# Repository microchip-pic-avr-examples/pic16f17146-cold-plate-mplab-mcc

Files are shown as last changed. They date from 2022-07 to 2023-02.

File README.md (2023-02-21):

MCHP (https://www.microchip.com)

# Intelligent Cooling Plate with PIC16F17146

Packed with more peripherals than I/O pins, this intelligent cooling plate — the cold plate — cools its metal surface and anything on top of it. This system is controlled by a single 20-pin, 8-bit microcontroller (MCU), which performs temperature measurements, peltier current monitoring, user interface control and safety functions. The MCU can handle this task single-handedly due to its wide array of Core Independent Peripherals (CIPs).

This README covers a usage guide and a functionality overview of the intelligent cooling plate. This is not an end product, but a demonstration of the expanding capabilities of microcontrollers. Rebuilding this demo in its entirety is possible, but it's purpose is to have pieces of its implementation copied into other practical designs. All Printed Circuit Board (PCB), Computer-Aided Design (CAD) files and nonstandard Bill of Materials (BOM) components are included in the repo for reference. A more in-depth explanation of the functionality listed below can be found in [Application Note AN4889](https://www.microchip.com/en-us/application-notes/an4889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).  

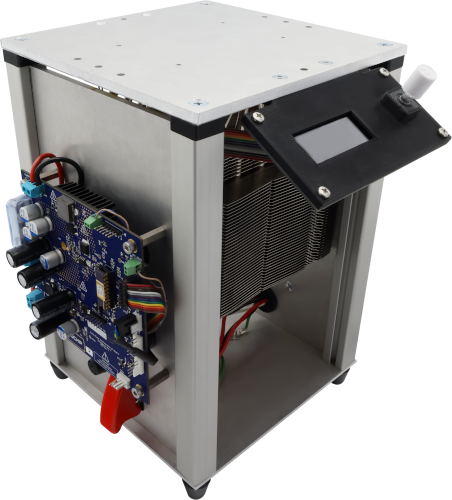
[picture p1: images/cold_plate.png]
The Cold Plate


## Related Documentation
- [PIC16F17146 Family](https://www.microchip.com/en-us/products/microcontrollers-and-microprocessors/8-bit-mcus/pic-mcus/pic16f17146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)
- [EA OLEDM204 Data Sheet](https://www.lcd-module.de/fileadmin/html-seiten/eng/pdf/doma/oledm204-ae.pdf)
- [CP85435 Peltier Plate Data Sheet](https://www.cuidevices.com/product/resource/cp85.pdf)
- [PS103J2 NTC Thermistors](https://www.littelfuse.com/products/temperature-sensors/leaded-thermistors/interchangeable-thermistors/standard-precision-ps/ps103j2.aspx)

## Software Used
- [MPLAB&reg; X IDE v6.0.5](https://www.microchip.com/en-us/tools-resources/develop/mplab-x-ide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) or newer
- [MPLAB XC8 v2.36.0](https://www.microchip.com/en-us/tools-resources/develop/mplab-xc-compilers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) or newer
- [MPLAB Code Configurator](https://www.microchip.com/en-us/tools-resources/configure/mplab-code-configurator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) (MCC)
- [MPLAB Mindi&trade; Analog Simulator](https://www.microchip.com/en-us/tools-resources/develop/analog-development-tool-ecosystem/mplab-mindi-analog-simulator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)

## Development Hardware Used

- [PIC16F17146](https://www.microchip.com/en-us/product/PIC16F17146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)
- [Curiosity Development Board (DM164137)](https://www.microchip.com/en-us/development-tool/DM164137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) (used during development)

## Major Functions
These are the major functions that are implemented on the microcontroller.

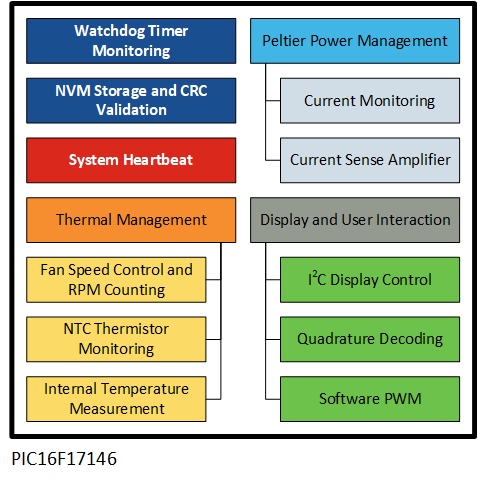
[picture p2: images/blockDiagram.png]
Block Diagram


**Current Monitoring and Measurement**  
- Integrated Operational Amplifier (OPAMP1)  
- Analog Comparators 1 and 2 (CMP1 and CMP2)  
- Digital-to-Analog Converters 1 and 2 (DAC1, DAC2) 
- Analog-to-Digital Converter with Computation (ADCC)
- Fixed Voltage Reference (FVR)

OPAMP1 is implemented as a current-sense amplifier, which outputs a magnified version of the small voltage across the current shunt resistor. The output of OPAMP1 is also used internally for monitoring and measurement. 

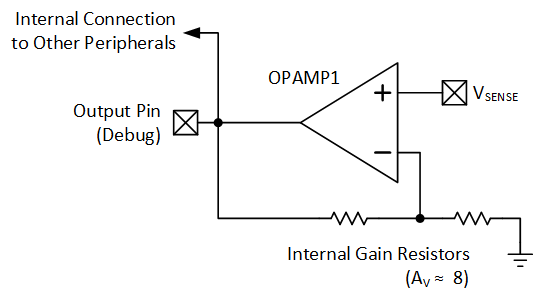
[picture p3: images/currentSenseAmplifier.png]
Current Sense Amplifier
  

The amplified current sense output of OPAMP1 is compared to a small, set voltage level (from DAC1) using CMP1. If the output is greater, then CMP1 is high, indicating current is flowing through the system.

DAC2/CMP2 work in the same way, but are used to detect overcurrent. If the DAC2 value is exceeded by the output of OPAMP1, the MCU shuts down the Peltier plate.

Additionally, the current is measured for telemetry by the ADCC, with the FVR providing the appropriate voltage reference.

**Cold Plate, Heat Sink, and MCU Temperature Monitoring**
- Analog-to-Digital Converter with Computation (ADCC)
- Fixed Voltage Reference (FVR)
- Temperature Indicator Module (TEMP)

The microcontroller measures the temperature of the top plate and its heat sink using Negative Temperature Coefficient (NTC) thermistors. It also monitors the internal temperature of the MCU die with the TEMP peripheral. The ADCC uses the FVR to ensure measurements are stable, and to provide the appropriate voltage for the TEMP peripheral. 

**Functional Safety Supported Setting Storage**
- Cyclic Redundancy Check (CRC) with Memory Scanner 
- Nonvolatile Memory (NVM) Control

Using the NVM and CRC CIPs, user settings are saved to EEPROM along with a CRC checksum. On start-up, the checksum is revalidated for data integrity. The CRC reduces code size and runs faster than the software could perform, by offloading it to the dedicated hardware.
 
**Protective System Monitoring**
- Timer 0 (TMR0)
- Windowed Watchdog Timer (WWDT)

Since the cold plate involves high currents and potentially hazardous temperatures, the WWDT is used to ensure periodic monitoring of the device is performed. If the WWDT is not triggered within a specific amount of time, the MCU resets. This way, if the firmware deadlocks, the system does not remain active, thus making sure safety is not compromised. TMR0 generates the base timing for the periodic self-check.

**Single-Speed Fan Control with Dual Fan Speed Monitoring**
- Pulse Width Modulator with Compare 2 (PWM2)
- Timer 2 (TMR2) and Timer 4 (TMR4)

To cool the Peltier plate, a PWM CIP is used to generate a speed control signal for the system fans. This allows the fans to ramp up and down depending on the conditions of the system. Additionally, the tachometer signals from the fans are monitored and counted by TMR2 and TMR4. If Fan 1 is not spinning (or stops spinning), the microcontroller will not power up the Peltier plate. 

**User Interface**
- Host Synchronous Serial Port 1 (MSSP1), in I<sup>2</sup>C mode
- Timer 1 (TMR1) and Timer 3 (TMR3)
- Configurable Logic Cell 1 and 2 (CLC1 and CLC2)
- Pulse Width Modulator with Compare 1 (PWM1)

The user interacts with the cold plate through a push button rotary encoder and an OLED display. The OLED is controlled with an on-chip MSSP1 peripheral via I<sup>2</sup>C. Since there is dedicated MSSP hardware, the CPU can load data into the module, rather than bit-banging the I/O lines. 

The rotary encoder inputs connect into two CLC CIPs to convert the signals into clockwise and counter-clockwise pulses (depending on direction). The pulses go into TMR1 and TMR3, which act as counters. The CPU can read the counters later to calculate the net rotation.

Lastly, the rotary encoder has two built-in LEDs—an orange and a blue LED. Using PWM1, these LEDs are used for a visual indication of the cold plate status:

| Color | Cold Plate Status |
| --- | --- |
| Breathing Purple | Standby |
| Breathing Blue | Actively Cooling |
| Solid Blue | At the Target Temperature |
| Solid Orange | Error |

**Debug Print**
- Enhanced Universal Synchronous Asynchronous Receiver
Transmitter (EUSART1)

EUSART1 is used to transmit debug messages from the MCU. It is set up to run at 115200 baud, 8 data bits and 1 stop bit.

## Operation

On boot, a standby screen shows the current plate temperature, the set temperature, and whether the product is in demo mode (which limits the lowest temperature for safety).

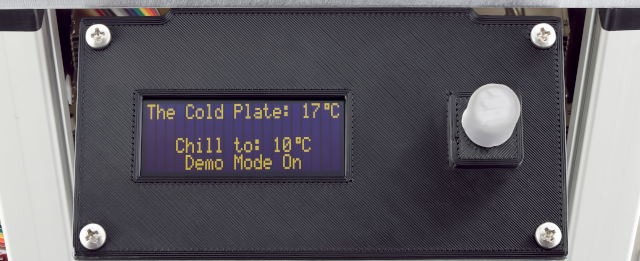
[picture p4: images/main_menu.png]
Main Menu


Pressing the rotary encoder button brings up a menu that can be used to change various running parameters:

| Name | Function |
| --- | --- |
| Go Back | Returns to Standby screen |
| Start | Turns on plate, goes to running status screen |
| Set Temperature | Changes target temperature |
| Hysteresis | Configures temperature hysteresis |
| Change Units | Selects Celsius or Fahrenheit units|
| Show Icons | Displays text or icons in running status screen |
| About | Lists developer and version info |
| Demo Mode Toggle | Password protected way to disable demo mode|

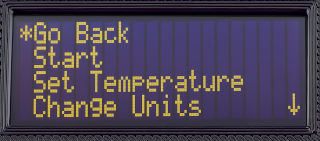
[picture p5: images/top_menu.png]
Top Menu

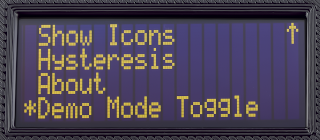
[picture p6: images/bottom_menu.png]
Bottom Menu


Upon pressing Start, the MCU begins checking for various errors. If all checks pass, the plate power is enabled and the user is brought to a running status screen which shows:

- Target temperature of the plate
- Current temperature of the plate
- MCU temperature
- Current Peltier current
- Cooling fan RPM

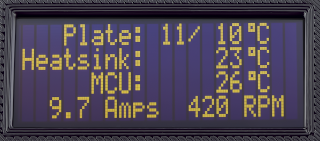
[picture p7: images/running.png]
Running Menu


If an error occurs, power to the plate is cut, and a troubleshooting error message displays on the screen. Press the rotary encoder to clear the error and return to the standy screen. If the error is not remedied and the plate is started again, it will loop back to the same error screen.

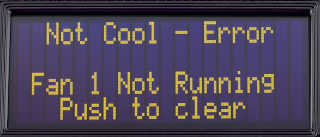
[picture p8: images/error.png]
Error Menu


Below is a list of the various possible errors that are continuously checked for during running operation:

| Name | Error Code | Cause |
| ---- | --- |--- |
| PELTIER_FAN1_ERROR | 1 | The heat sink fan is unplugged |
| PELTIER_OVERCURRENT_ERROR | 2 | More current is pulled than the software allows |
| PELTIER_POWER_ERROR | 3 | No power is detected when the plate should be pulling current |
| PELTIER_GAIN_ERROR | 4 | The gain of the operational amplifier exceeds expected tolerance
| PELTIER_INT_OVERHEAT | 5 | Internal MCU temperature is too hot (70&deg;C)|
| PELTIER_HEATSINK_OVERHEAT | 6 | Heat sink is too hot (80&deg;C)|
| PELTIER_SENSE_HOT_OPEN | 7 | Thermistor for the heat sink is disconnected |
| PELTIER_SENSE_COLD_OPEN | 8 | Thermistor for the plate temp is disconnected |
| PELTIER_PLATE_TEMP_LIMIT | 9 | Cold plate is below safe temperature |
| PELTIER_EEPROM_WRITE_FAIL | 10 | Internal EEPROM written value does not match read value. |

Once started, pressing the rotary encoder button and selecting `Cancel` stops the plate and returns to the standby menu.

## Summary
This README covered a brief overview of the functionality of the cold plate and how to operate it.

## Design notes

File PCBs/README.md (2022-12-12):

# Important Information about PCBs

- Only Rev A was tested, Rev B has not been tested.
    - Power stage on Rev A was modified for linear topology.
    - Recommended to build Rev B, not A
- Thermal conductors are for testing purposes. 
    - Only THM_C1 is needed for an implemented function (implementing OTP on the PCB).

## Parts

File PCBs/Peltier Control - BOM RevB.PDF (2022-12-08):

Comment | Value | Footprint | Part Number | Designator | Quantity
Capacitor | 0.1uF | 0805 | | C1, C9, C13, C30 | 4
Electrolytic Capacitor | 270uF | 12.5mm Electrolytic Capacitor | 100ZLJ220M12.5X25 | C2, C5, C10, C15 | 4
Capacitor | 10uF | 0805 | | C3, C4, C19, C28 | 4
Electrolytic Capacitor | 22uF | 10mm Electrolytic Capacitor | A759MS226M2AAAE045 | C6, C11, C16, C20, C34 | 5
Capacitor | 1uF | 1206 | | C7, C8 | 2
Capacitor | 10uF | 1210 | | C12 | 1
Capacitor | 330nF | 0805 | | C17 | 1
Capacitor | 1uF | 0805 | | C22, C24, C25, C27, C29, C31 | 6
Capacitor | DNP | 0805 | | C32, C33 | 2
48V - 15V | | TB002-500-02BE | TB002-500-02BE | CONTROL PWR, PELTIER PWR | 2
LED | | 0805 for LED | | D2, D4, D5, D6 | 4
Schottky | | SOD-128 | PMEG6030EVPX | D3 | 1
Diode | | SOT-23-3 | BAS16LT1G | D8, D10 | 2
Connect to Earth | | TB002-500-02BE | TB002-500-02BE | EARTH CONN | 1
ESD Diode Array | | SOIC-16 | SP720ABG | ESD1 | 1
Fuse | | 4250 Fuse Holder | 4250 | F1 | 1
Fuse | | 1206 Fuse | SF-1206S300W-2 | F2 | 1
Fan Header | | 0470531000 | | FAN1, FAN2 | 2
SMD Metal Jumper on PCB | | 0805 PCB Jumper | | J1, J2 | 2
Inductor | 5.2uH | CDRH104R | CDRH104RNP-5R2NC | L3 | 1
2-Pos Terminal Block | | 691210910002 | 691210910002 | NTC_COLD, NTC_HOT | 2
To Peltier Plate(s) | | TB002-500-02BE | TB002-500-02BE | PELTIER_CONN | 1
PICKIT 4 Header | | HDR1X6 | | PICKIT | 1
PTC Fuse | 200mA | PTC 0805 | MF-PSHT020KX-2 | PTC1, PTC2 | 2
PTC Fuse | 50mA | PTC 0805 | MF-PSHT005KX-2 | PTC5, PTC6 | 2
NMOS | | TO-252 | FDD390N15ALZ | Q1 | 1
Resistor | 10k | 0805 | | R1, R6, R13, R14, R16, R22, R23, R25 | 8
Resistor | 470 | 0805 | | R2 | 1
Resistor | 1k | 0805 | | R3, R24 | 2
Resistor | 4.7k | 0805 | | R4, R7, R8 | 3
Resistor | 10m | Wide 1206 | CSNL1206FT1L00 | R5 | 1
Resistor | 27k | 0805 | | R9, R10, R19, R28 | 4
Resistor | 0 | 0805 | | R11, R12 | 2
Resistor | 140k | 0805 | | R15 | 1
Resistor | 100 | 0805 | | R17, R18, R26, R27 | 4
NTC | 10k @ 25C | 0805 | SM103J1K | R20 | 1
Resistor | DNP | 0805 | | R21 | 1
Resistor | 2.2k | 0805 | | R29 | 1
SPST Switch | | PTS636-THT | | RST_SW | 1
Header 6 | | HDR1X6 | | SERIAL_DEBUG | 1
Thermal Conductor | | 0805 | QB0805A40WYTD | THM_C1, THM_C2, THM_C3 | 3
Test Point | | Test Point, 40mil hole | 526x, [NoValue] | TP1, TP2, TP5, TP6, TP7, TP8, TP12, TP13, TP14, TP15, TP19, TP20, TP21, TP22 | 14
Test Point | | Test Point, 60mil SMD | | TP16, TP17, TP18 | 3
MCP1754S | | SOT-223-3 | MCP1754ST-5002E/DB | U1 | 1
PIC16F17146 | | PDIP-20 | | U2 | 1
TC1413(N), MOSFET Driver | | SOIC-8 | TC1413N | U3 | 1
MCP6566 | | SOT23-5 | | U4 | 1
MCP16363 | | VDFN 3x3x0.9 | MCP16363T-E/NMX | U6 | 1
Header 6X2 | | HDR2X6 | | UI_BOARD_CONN | 1
Zener | 7.5V | SOT-23-3 | BZX84B7V5-7-F | Z2 | 1

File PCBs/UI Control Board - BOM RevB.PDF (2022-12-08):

Comment | Value | Footprint | Quantity | Designator
3 Position SMD Jumper | | 3 Position 0805 | 2 | J1, J2
Capacitor | 0.1uF | 0805 | 4 | C1, C2, C5, C6
Capacitor | 2.2uF | 0805 | 2 | C3, C4
Capacitor | 10uF | 0805 | 2 | C9, C10
Capacitor | DNP | 0805 | 3 | C7, C8, C11
Header 2 | | HDR1X2 | 1 | EXT_BUTTON
Header 6X2 | | HDR2X6 | 1 | UI_BOARD_CONN
LED | | 0805 for LED | 4 | D1, D2, D3, D4
Mechanical Encoder with 2 LEDs and Switch | | PEL12D-4xxxS-Sxxxx | 1 | ENC1
OLED 4x20 Character Display | | EA OLEDM204 | 1 | DISP1
Resistor | 0 | 0805 | 1 | R8
Resistor | 1k | 0805 | 5 | R9, R10, R11, R12, R13
Resistor | 2.7k | 0805 | 1 | R14
Resistor | 10k | 0805 | 6 | R1, R3, R4, R5, R6, R7
Resistor | 910k | 0805 | 1 | R2
Resistor | DNP | 0805 | 2 | R15, R16
SPST Switch | | PTS636-THT | 1 | DISP_RST
Test Point | | Test Point, 60mil SMD | 5 | TP1, TP2, TP3, TP4, TP5

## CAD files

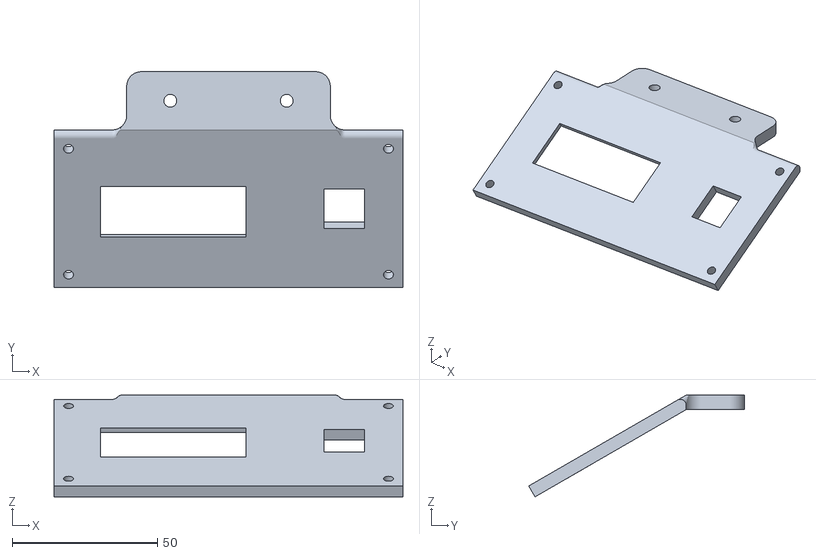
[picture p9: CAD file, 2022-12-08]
3D Prints/UI_mount.obj
120.0 x 74.1 x 35.0

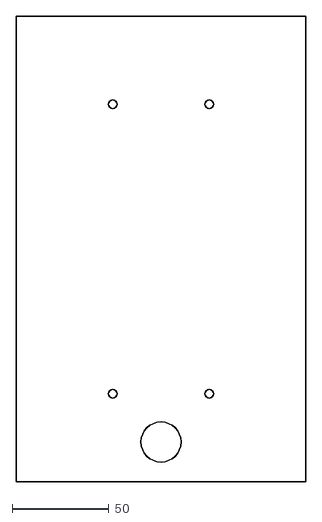
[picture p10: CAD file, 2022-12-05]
Mechanical Plates/PSU Mounting.dxf
150.0 x 241.3

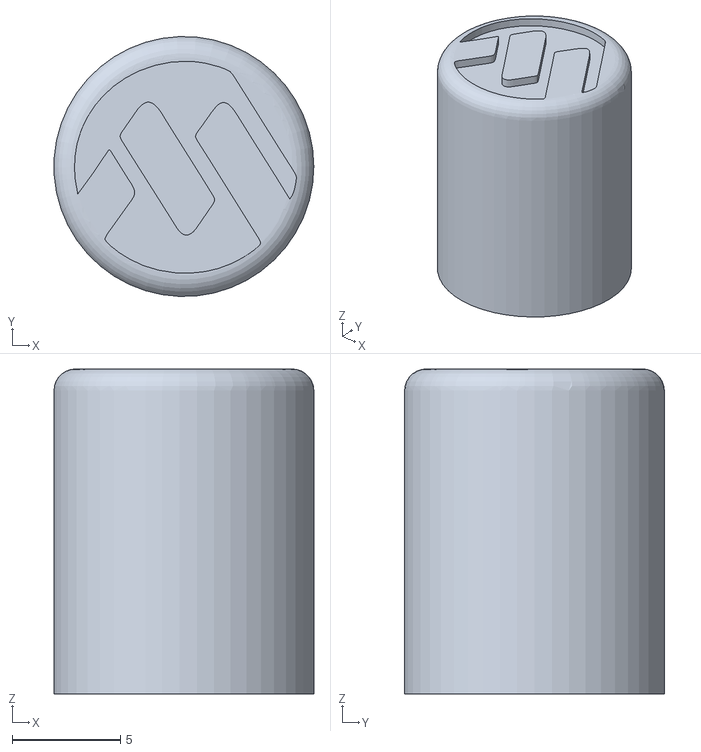
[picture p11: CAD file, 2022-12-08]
3D Prints/encoder_knob.obj
12.0 x 12.0 x 15.0

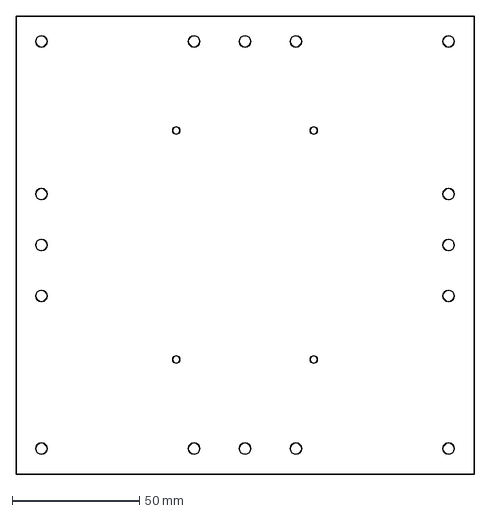
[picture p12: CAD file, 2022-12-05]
Mechanical Plates/Top Plate.dxf
180.0 x 180.0 mm

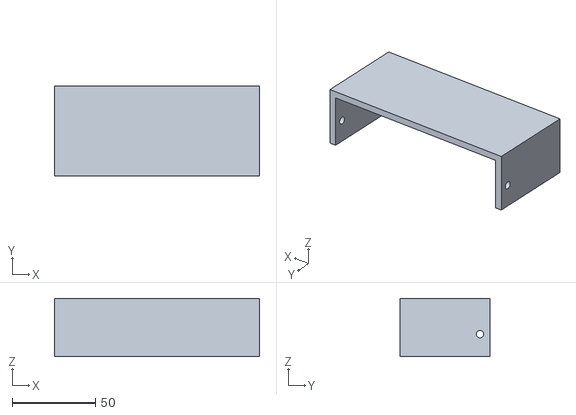
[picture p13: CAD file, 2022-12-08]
3D Prints/power_supply_cover.obj
123.0 x 54.0 x 35.0

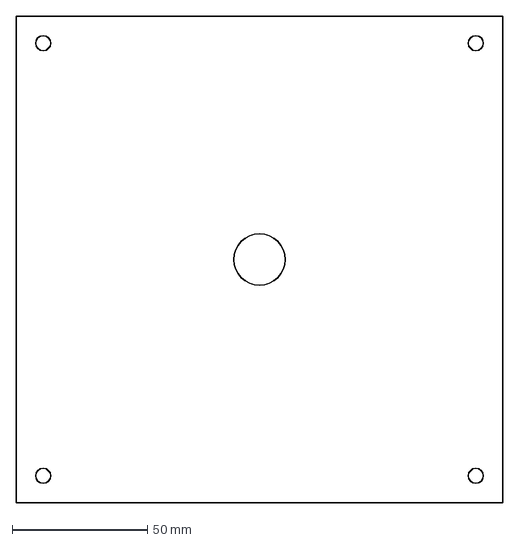
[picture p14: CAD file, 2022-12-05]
Mechanical Plates/Bottom Plate.dxf
180.0 x 180.0 mm

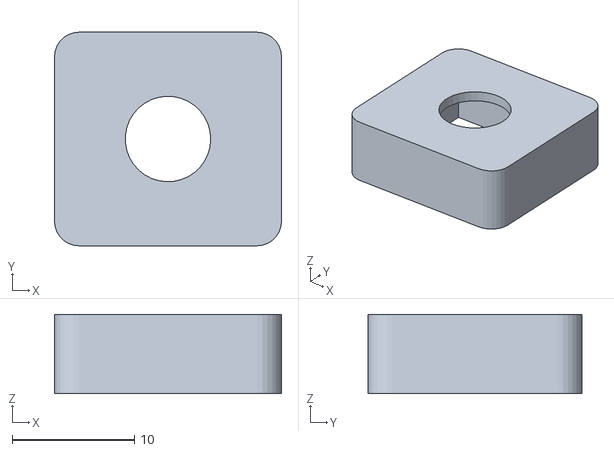
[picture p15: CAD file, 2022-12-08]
3D Prints/encoder_cover.obj
18.6 x 17.5 x 6.50

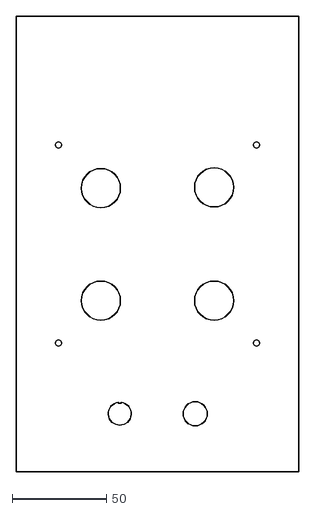
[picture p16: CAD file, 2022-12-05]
Mechanical Plates/PCB Mounting.dxf
150.0 x 241.3

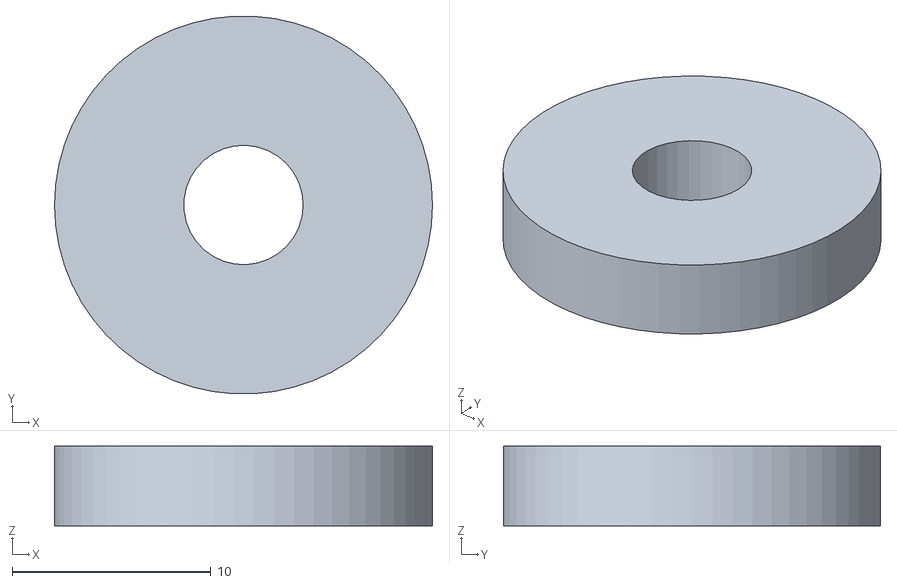
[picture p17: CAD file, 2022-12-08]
3D Prints/rubber_feet_spacer.obj
19.0 x 19.0 x 4.00

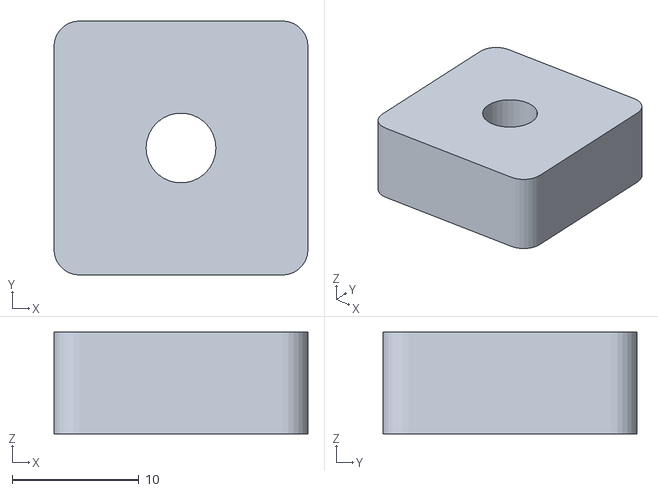
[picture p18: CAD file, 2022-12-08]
3D Prints/temperature_spacer.obj
20.0 x 20.0 x 8.00

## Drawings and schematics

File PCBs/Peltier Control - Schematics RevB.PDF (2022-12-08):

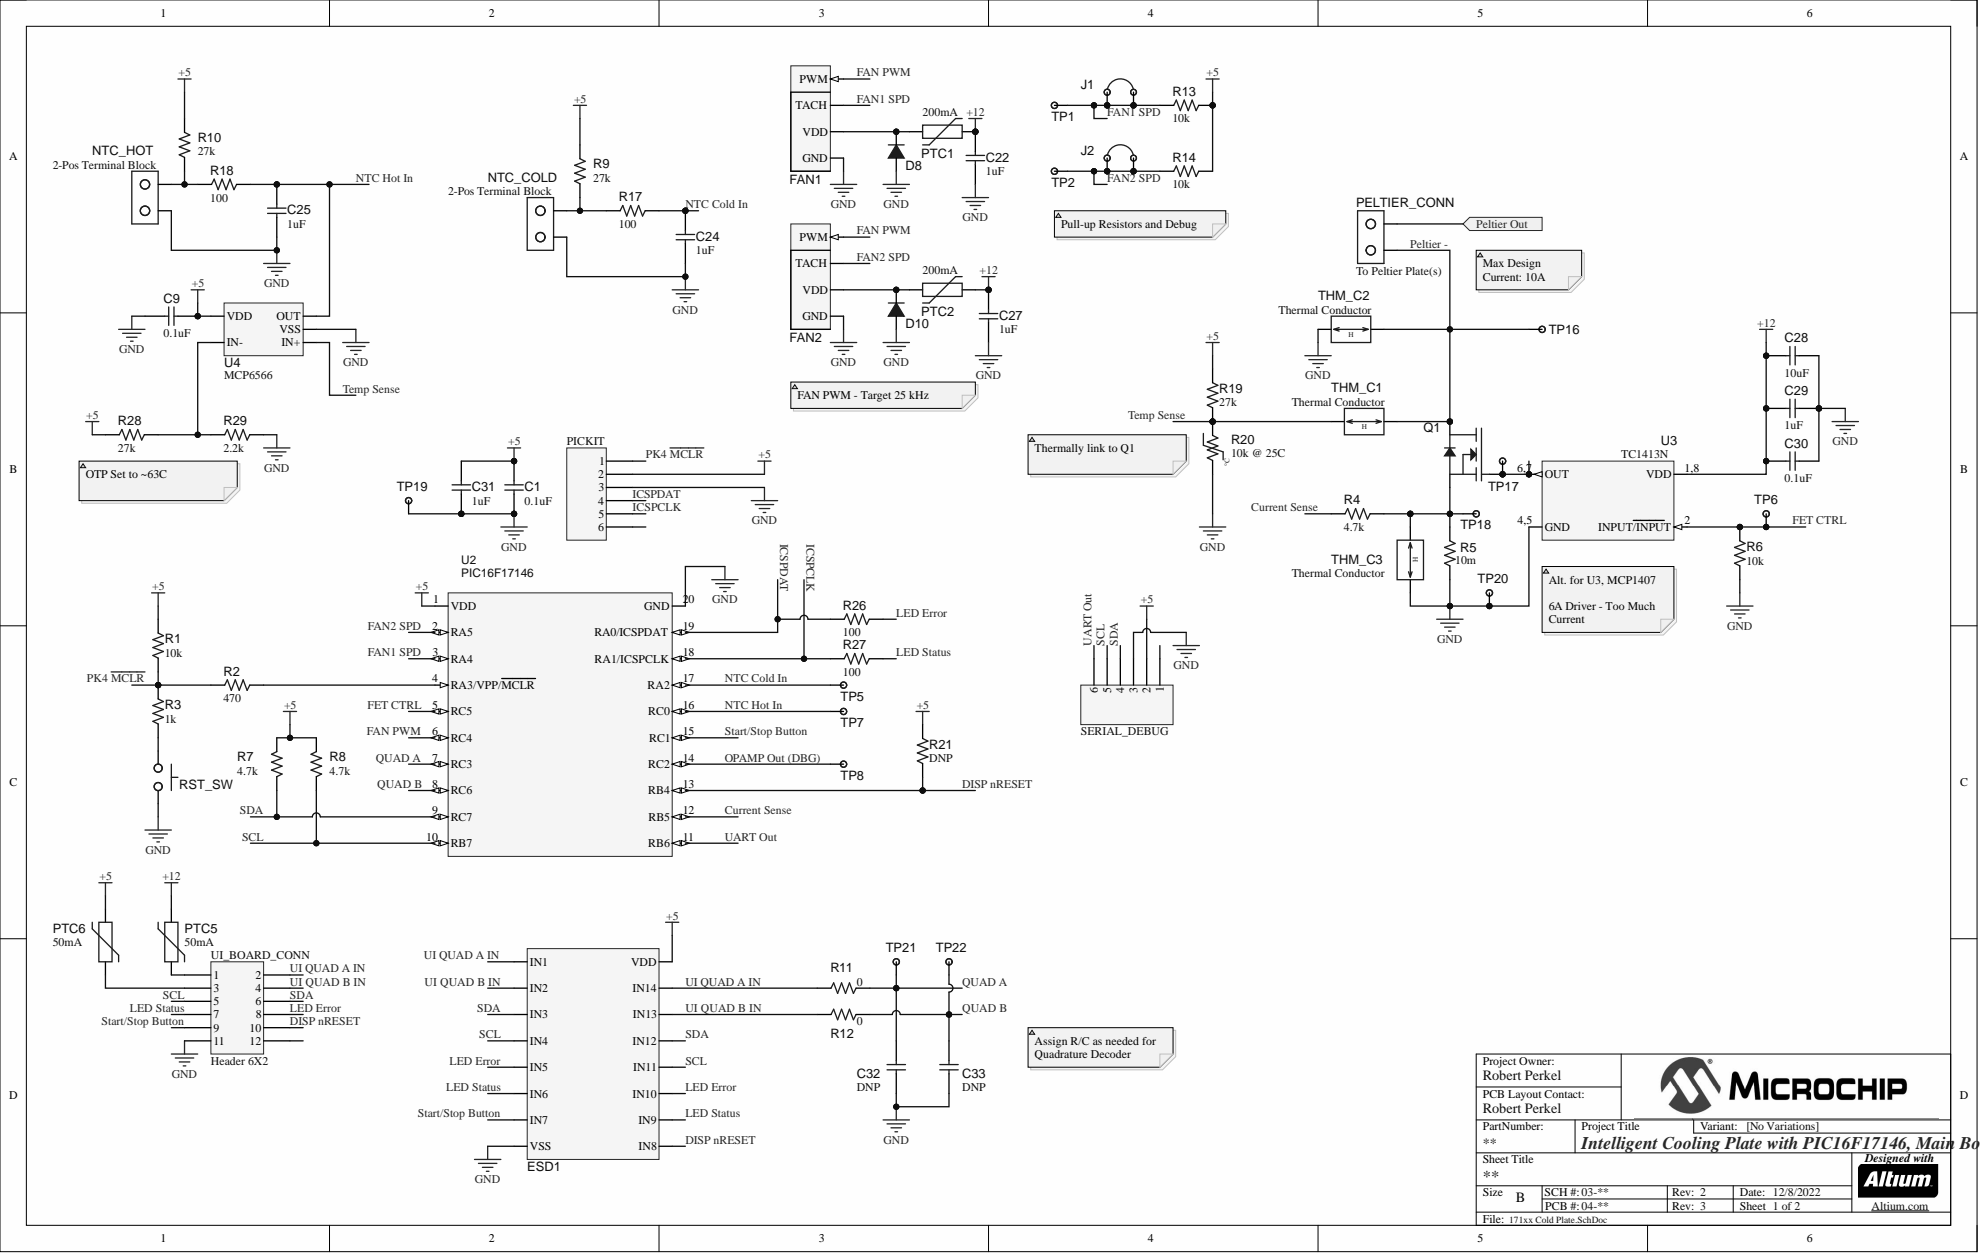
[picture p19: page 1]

Pull-up Resistors and Debug

FAN PWM - Target 25 kHz

Assign R/C as needed for
Quadrature Decoder

Project Title
Intelligent Cooling Plate with PIC16F17146, Main Board

Sheet Title ** | Designed with Altium.com

Size B | SCH #: 03-** | Rev: 2 | Date: 12/8/2022

PCB #: 04-** | Rev: 3 | Sheet

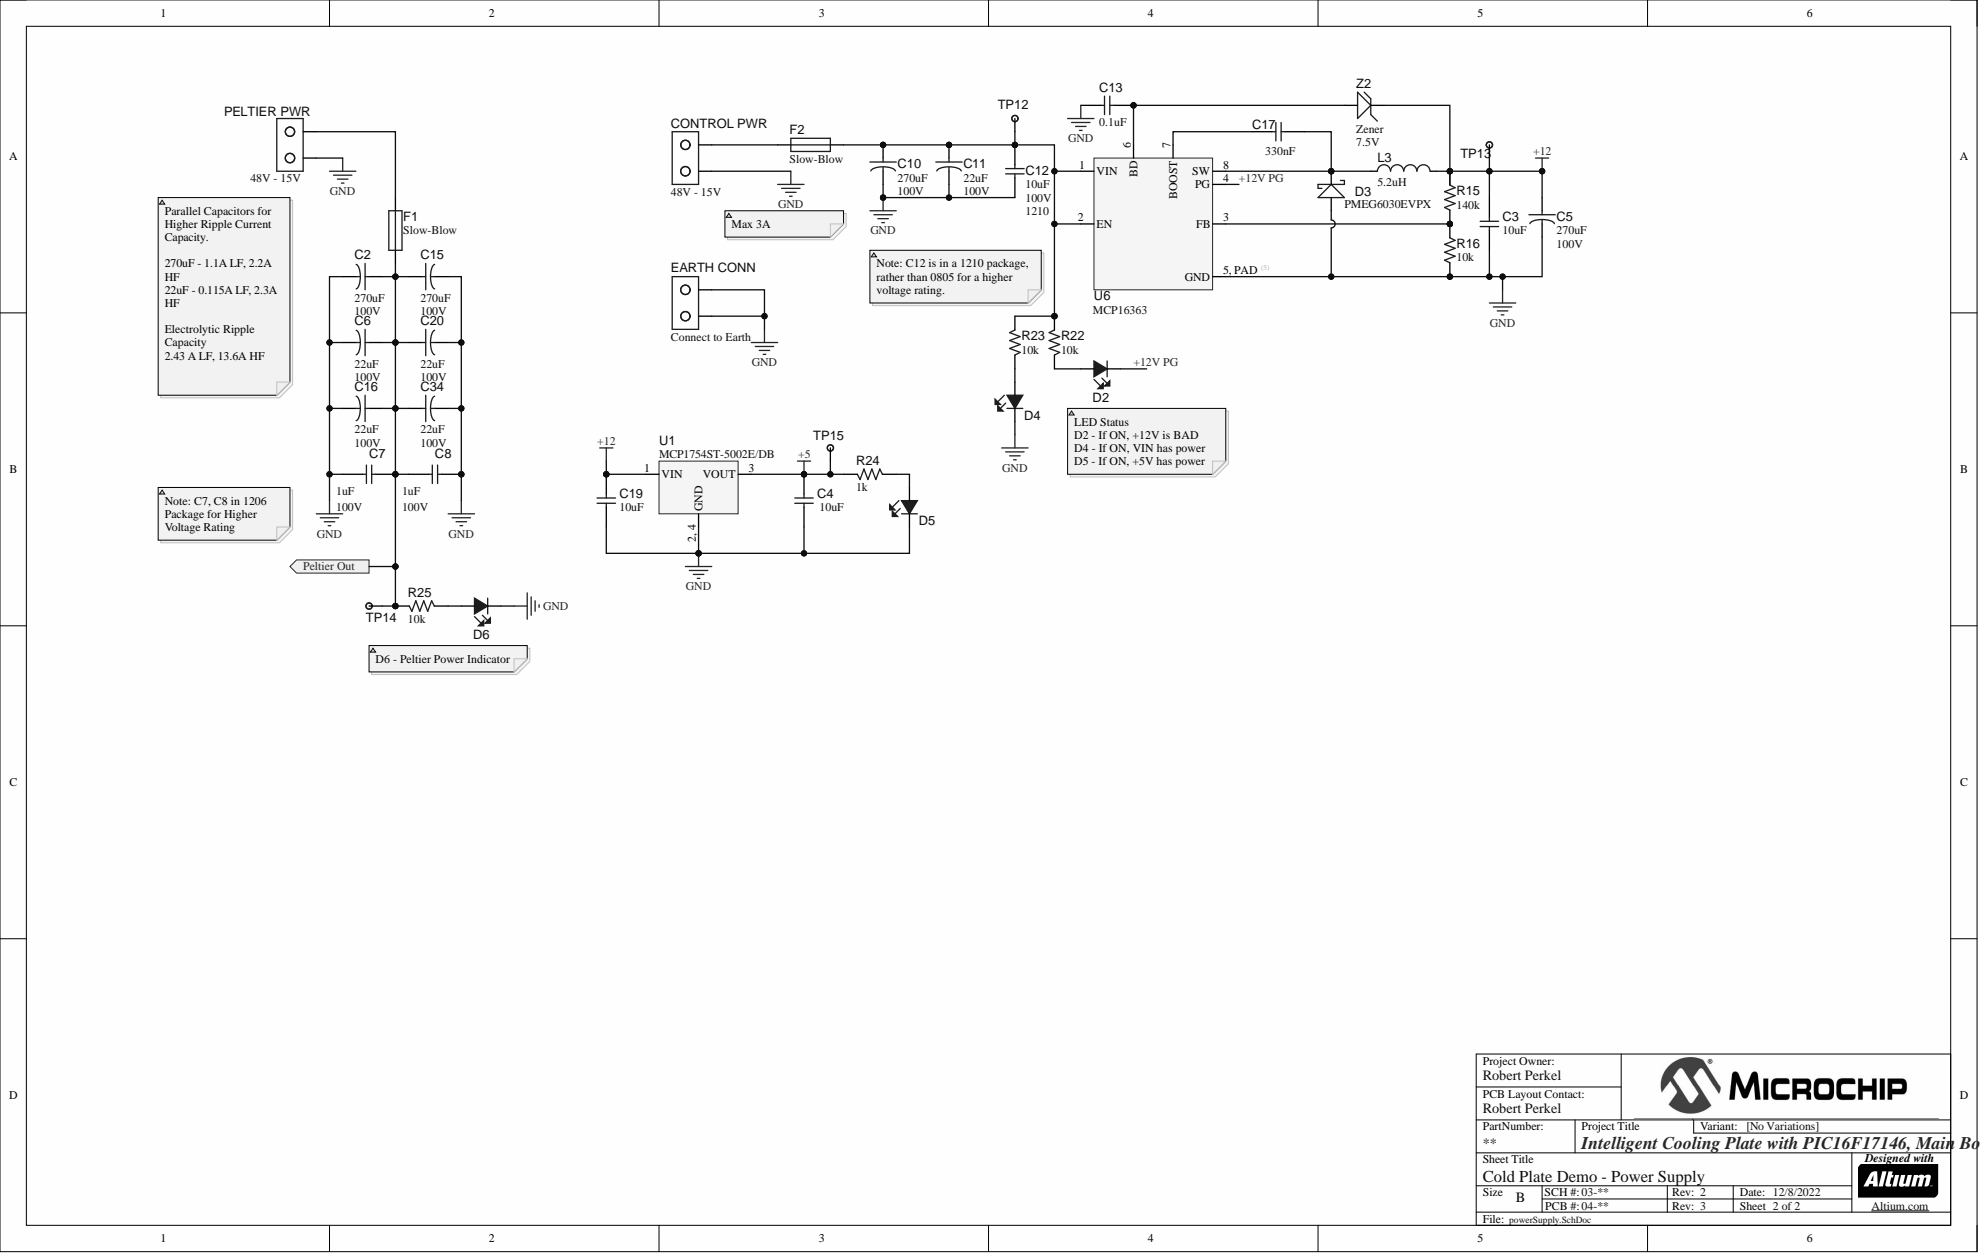
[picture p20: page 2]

Note: C12 is in a 1210 package,
rather than 0805 for a higher
voltage rating.

LED Status
D2 - If ON, +12V is BAD
D4 - If ON, VIN has power
D5 - If ON, +5V has power

Project Title
Intelligent Cooling Plate with PIC16F17146, Main Board

Sheet Title Cold Plate Demo - Power Supply | Designed with Altium.com

Size B | SCH #: 03-** | Rev: 2 | Date: 12/8/2022

PCB #: 04-** | Rev: 3 | Sheet

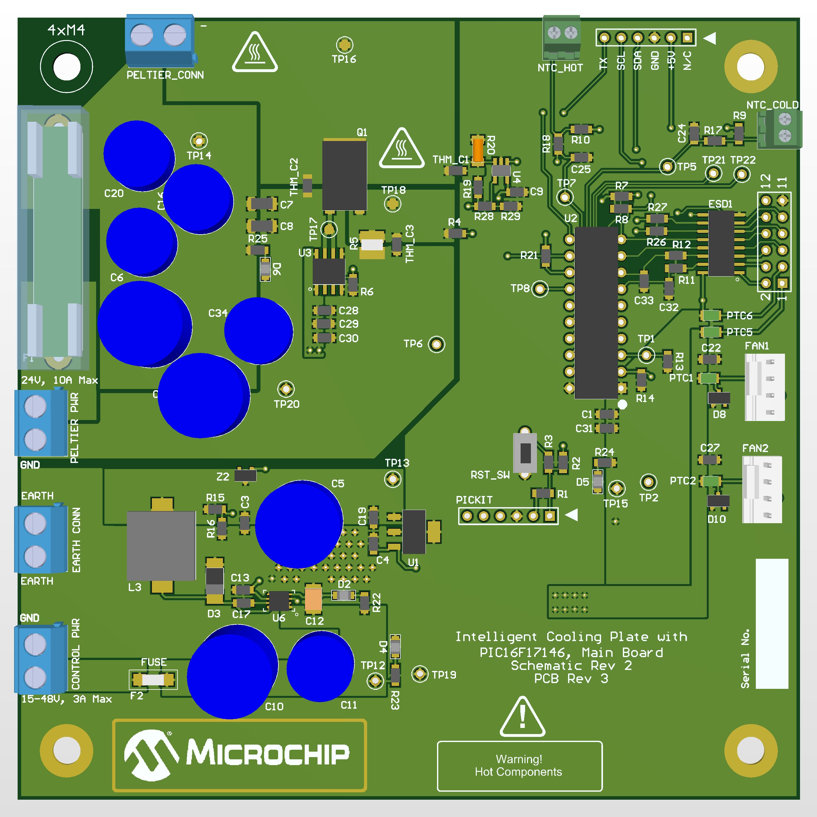
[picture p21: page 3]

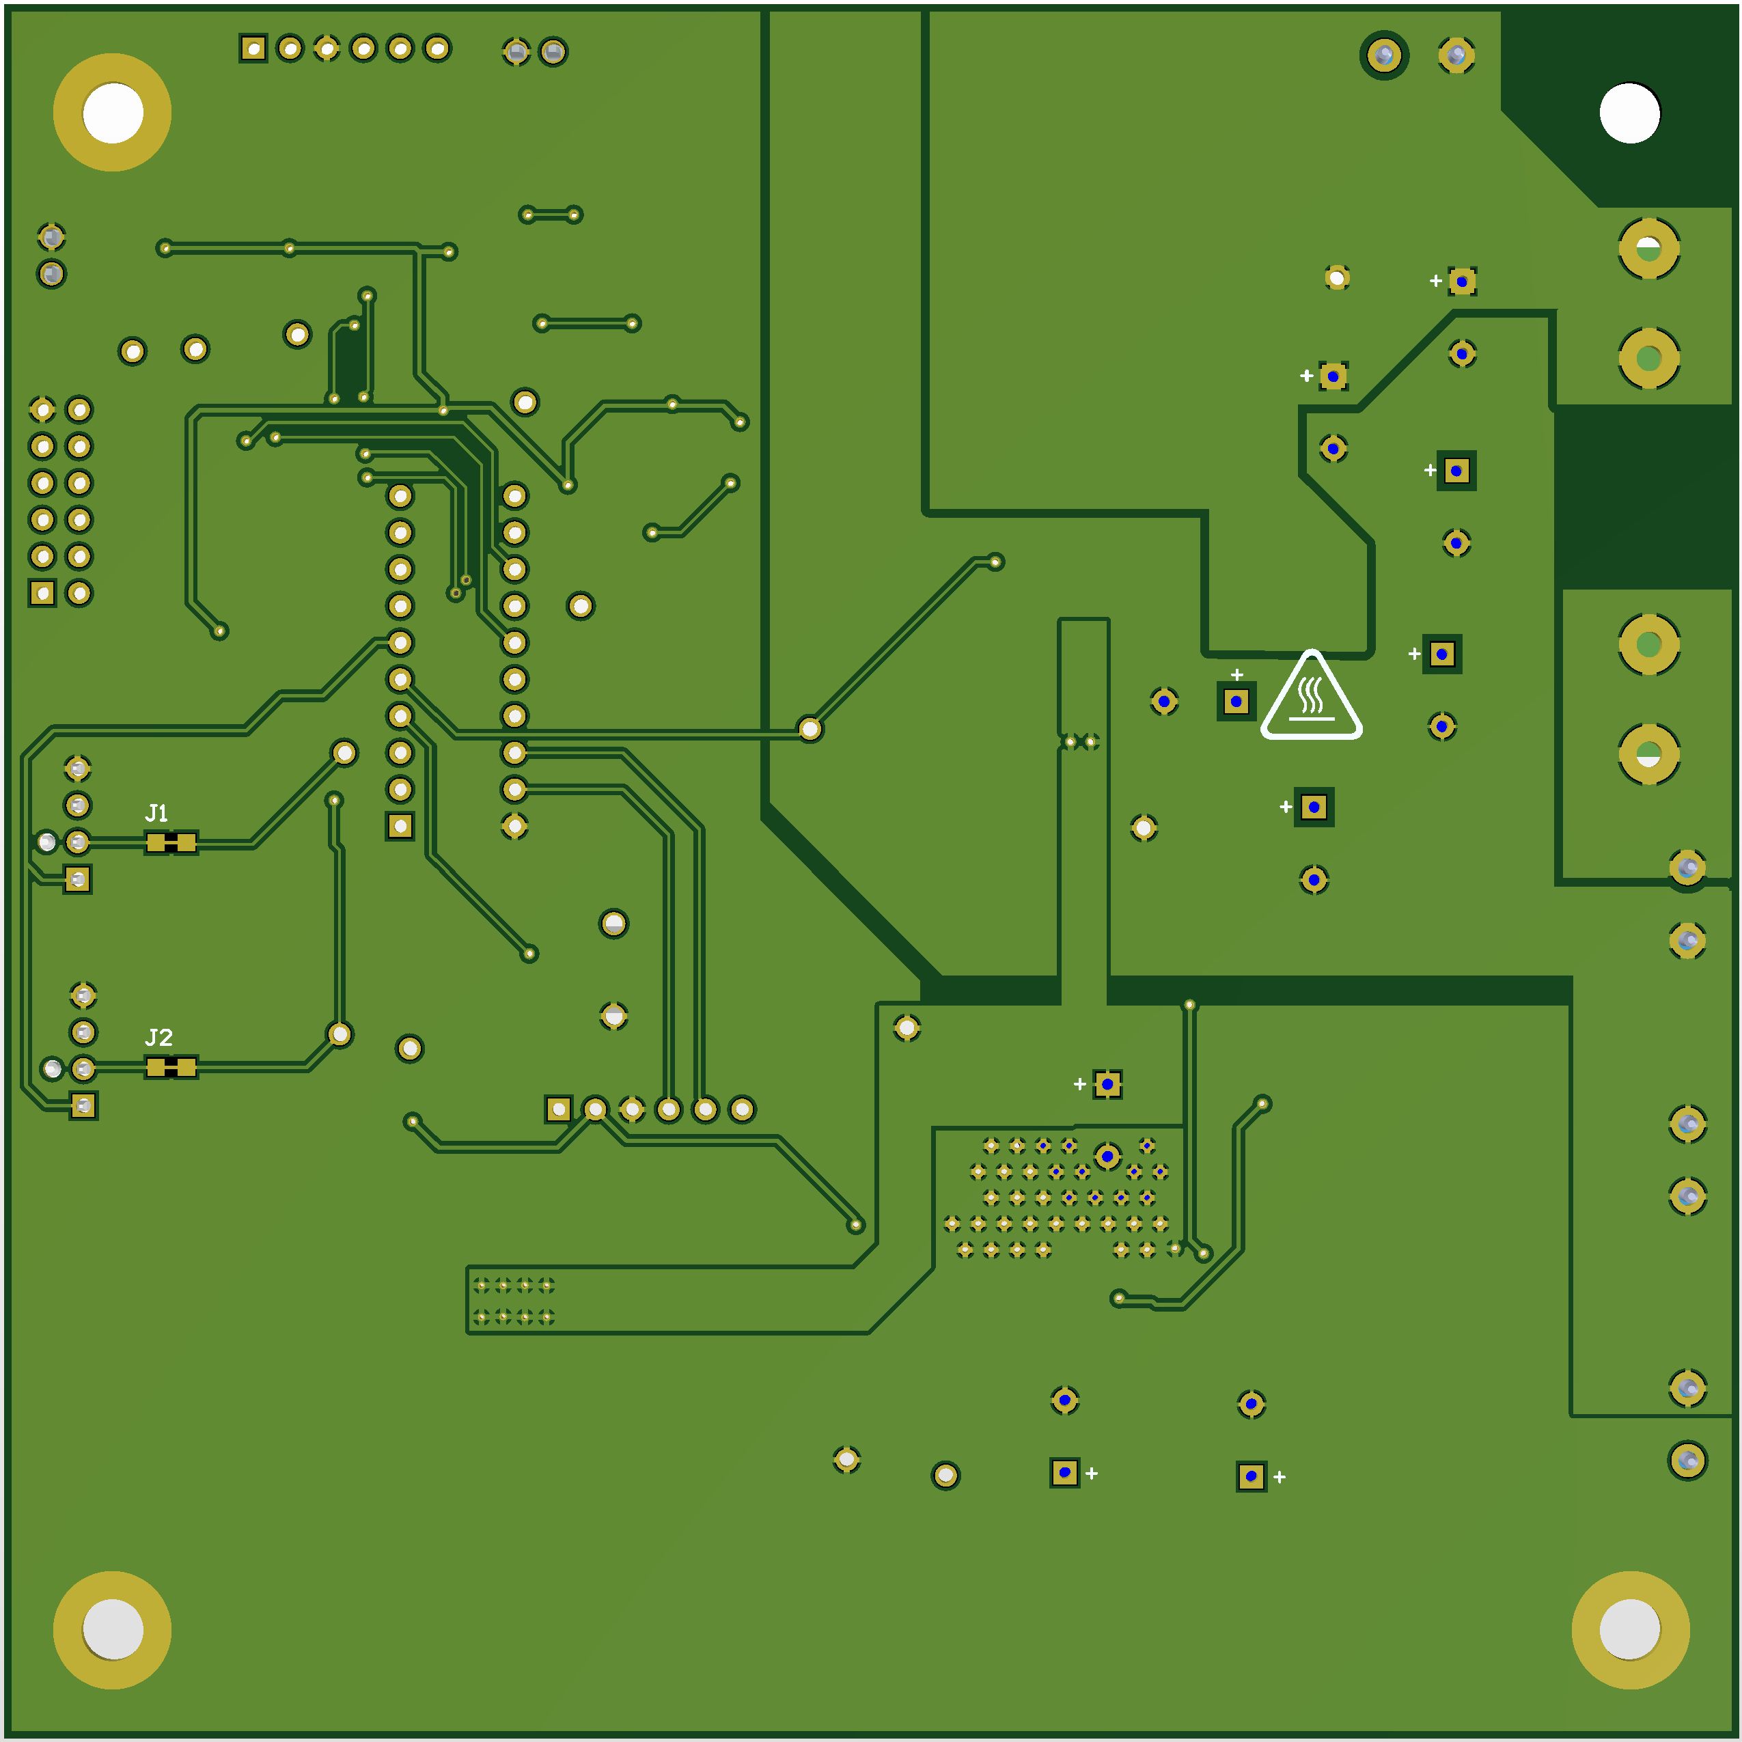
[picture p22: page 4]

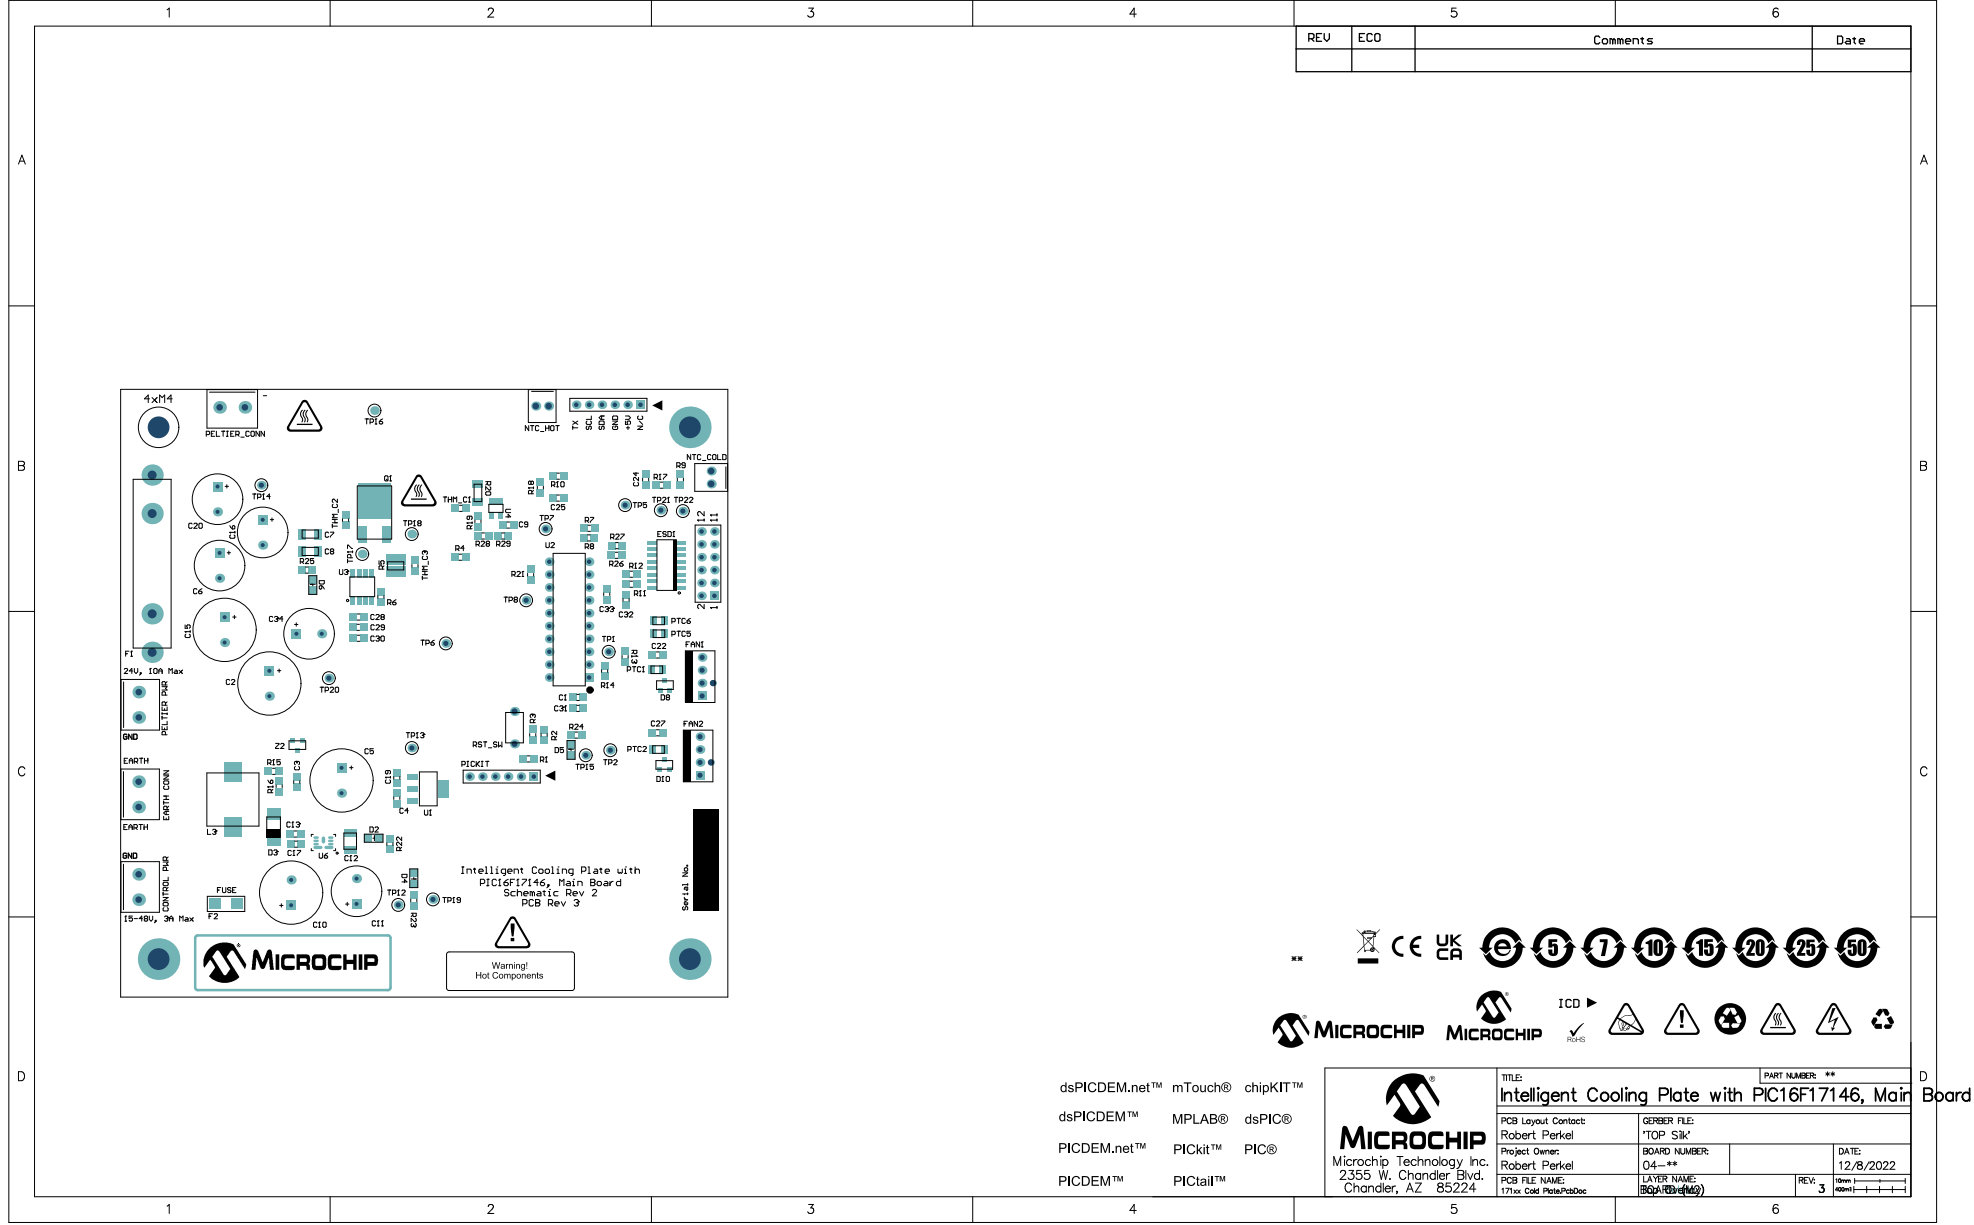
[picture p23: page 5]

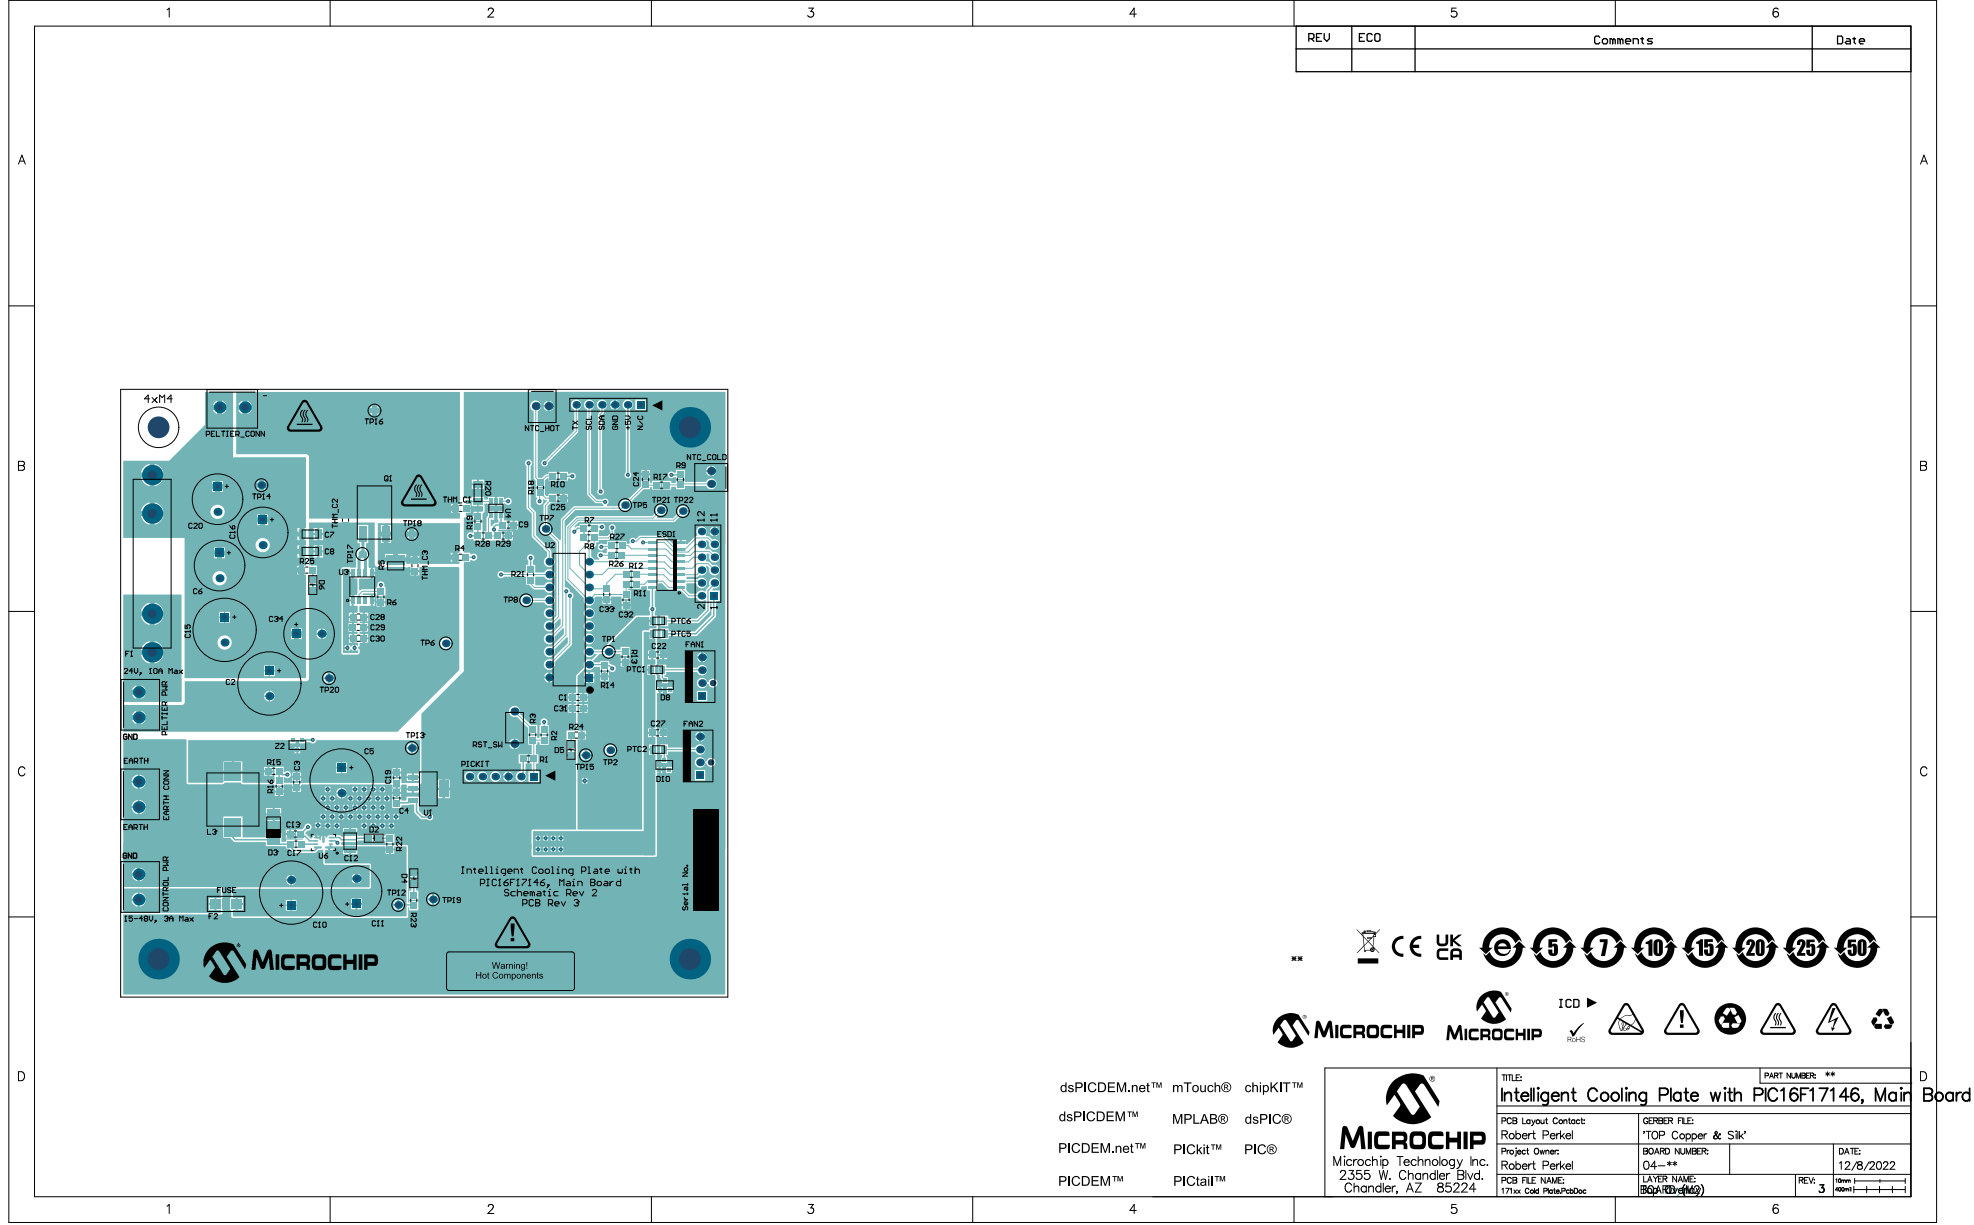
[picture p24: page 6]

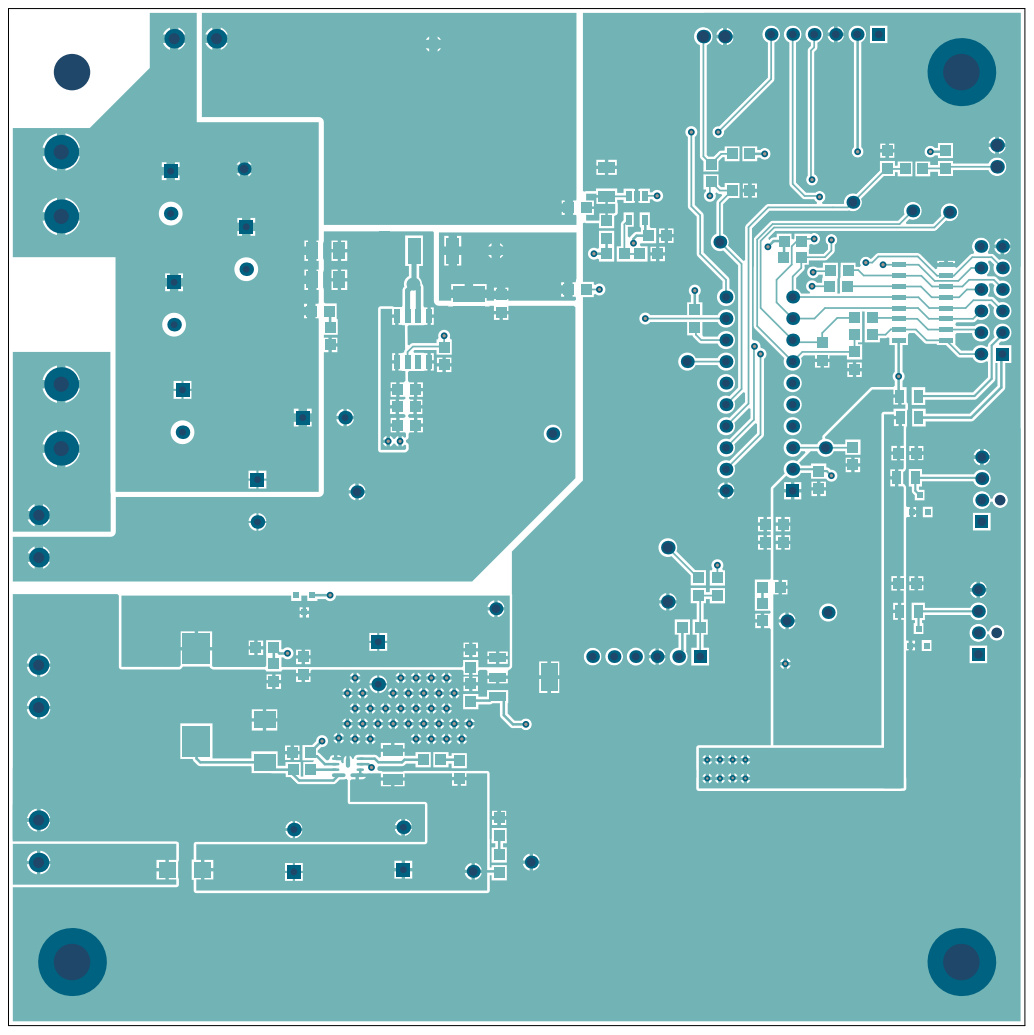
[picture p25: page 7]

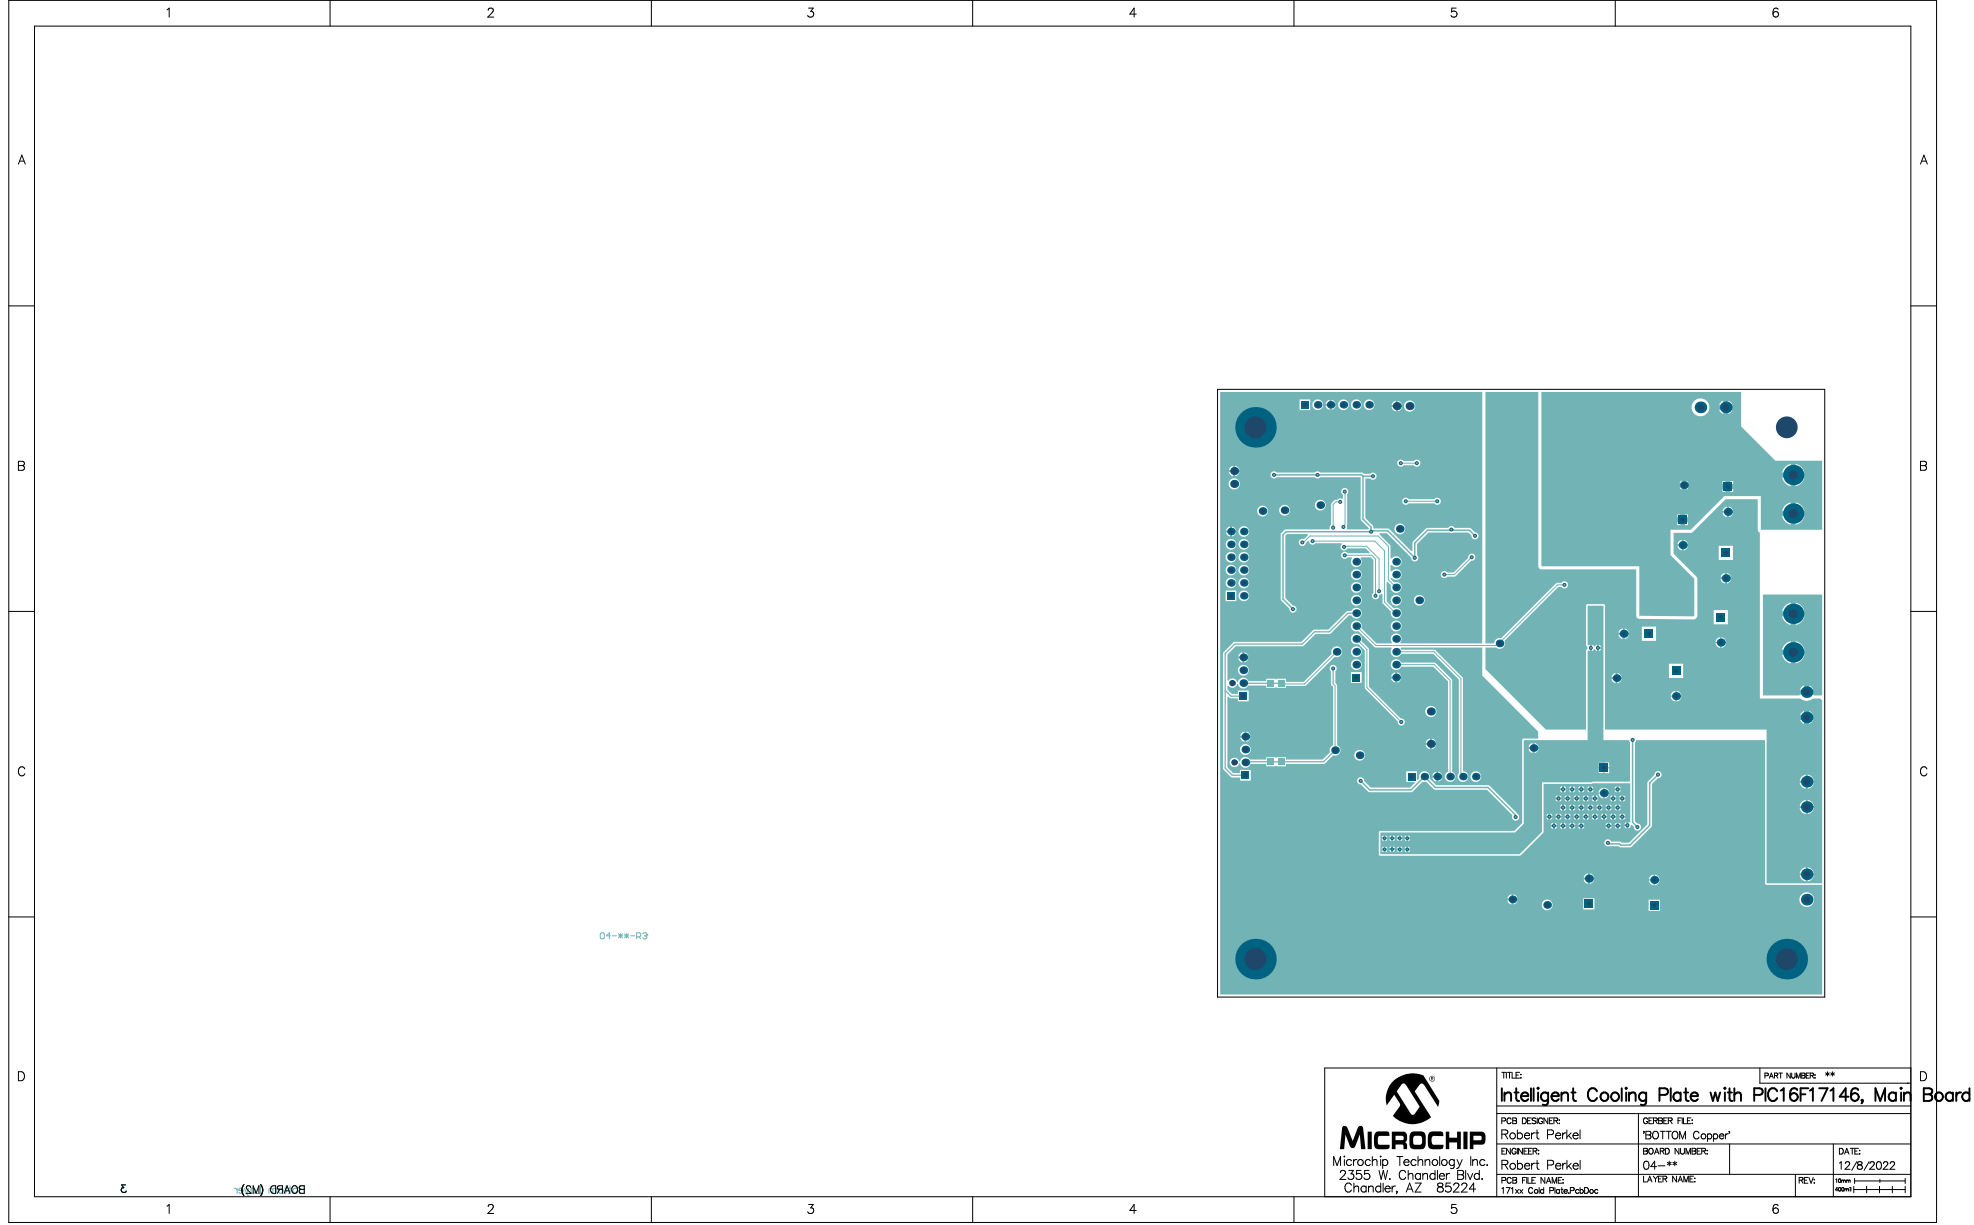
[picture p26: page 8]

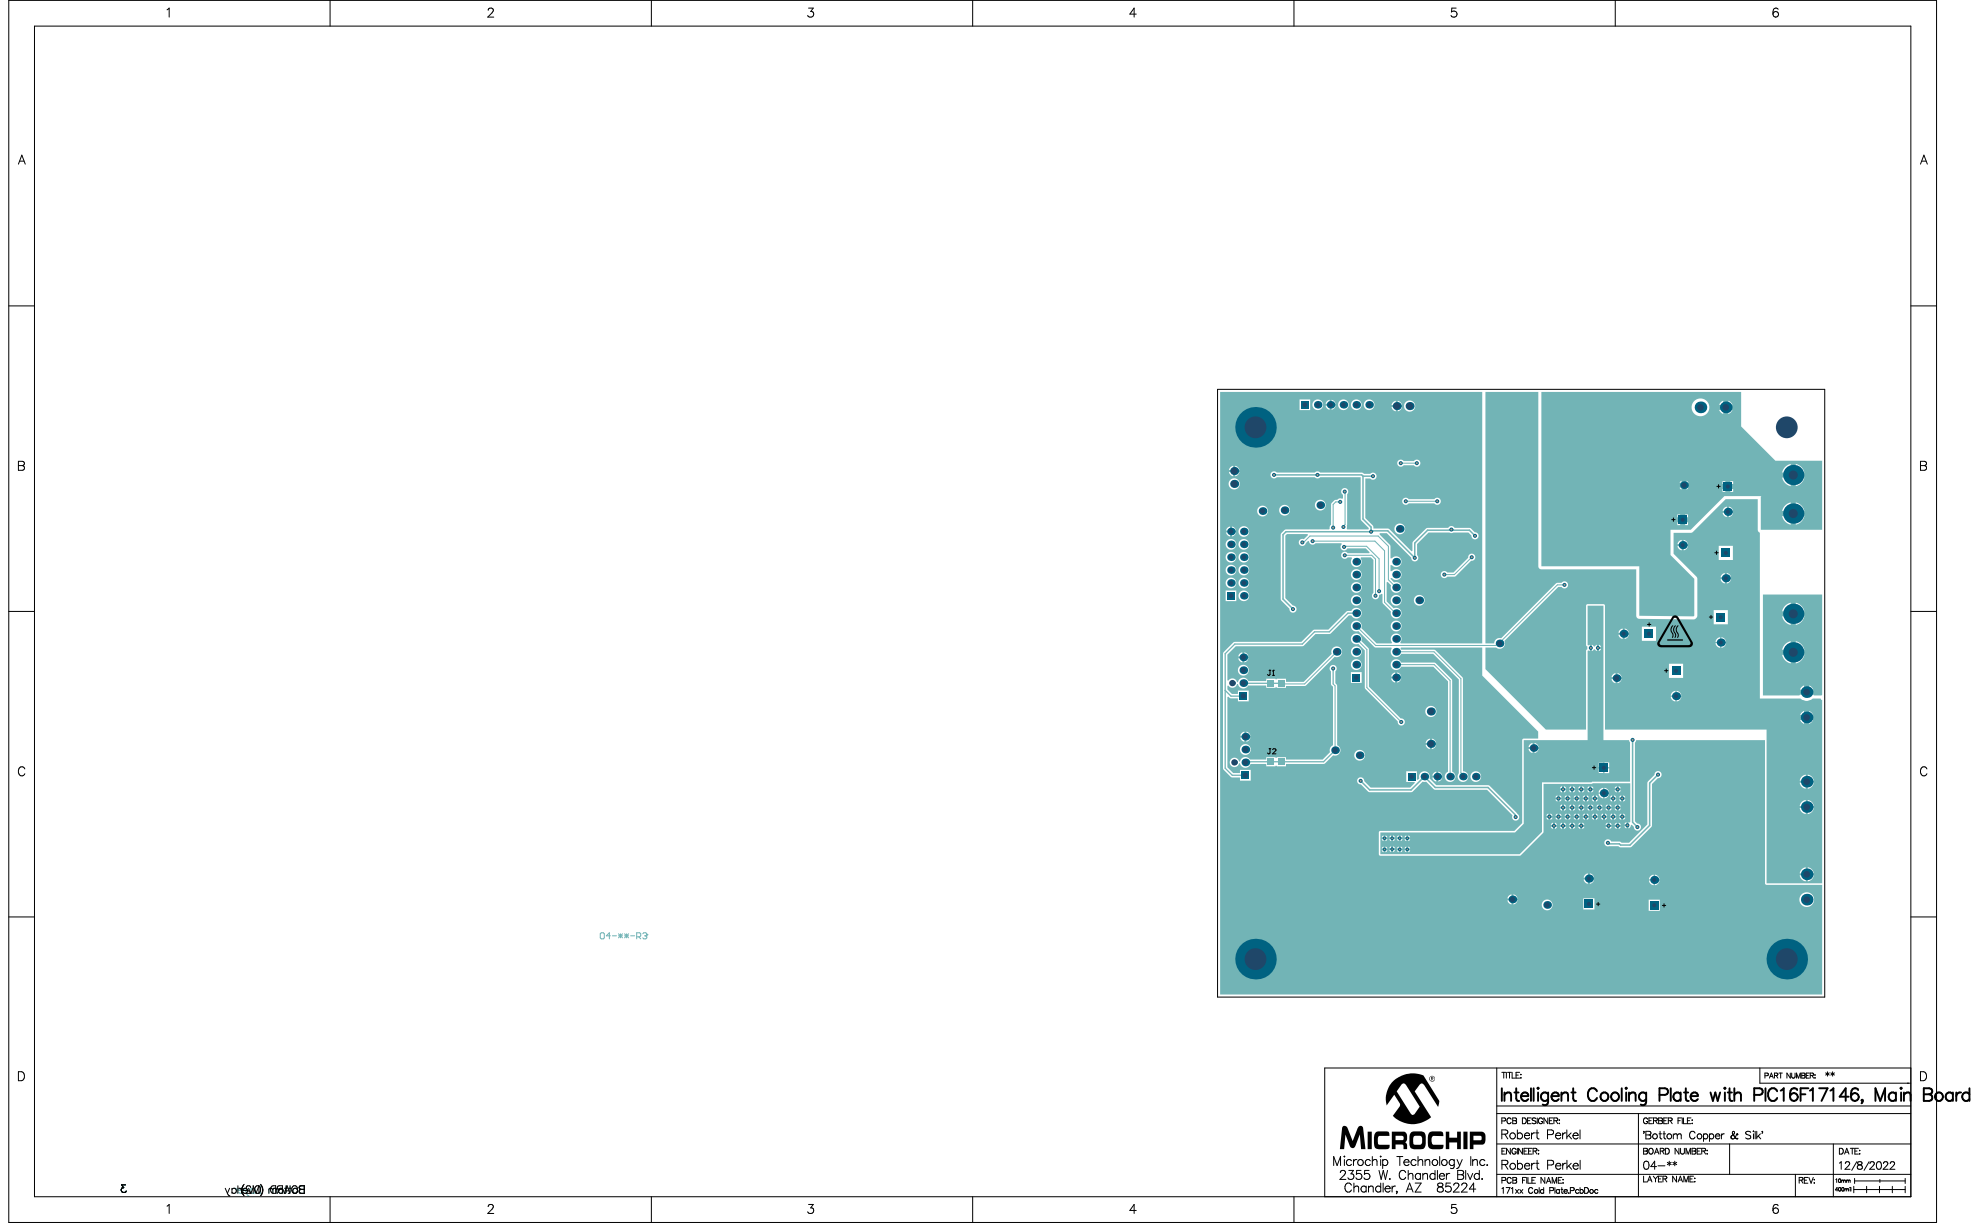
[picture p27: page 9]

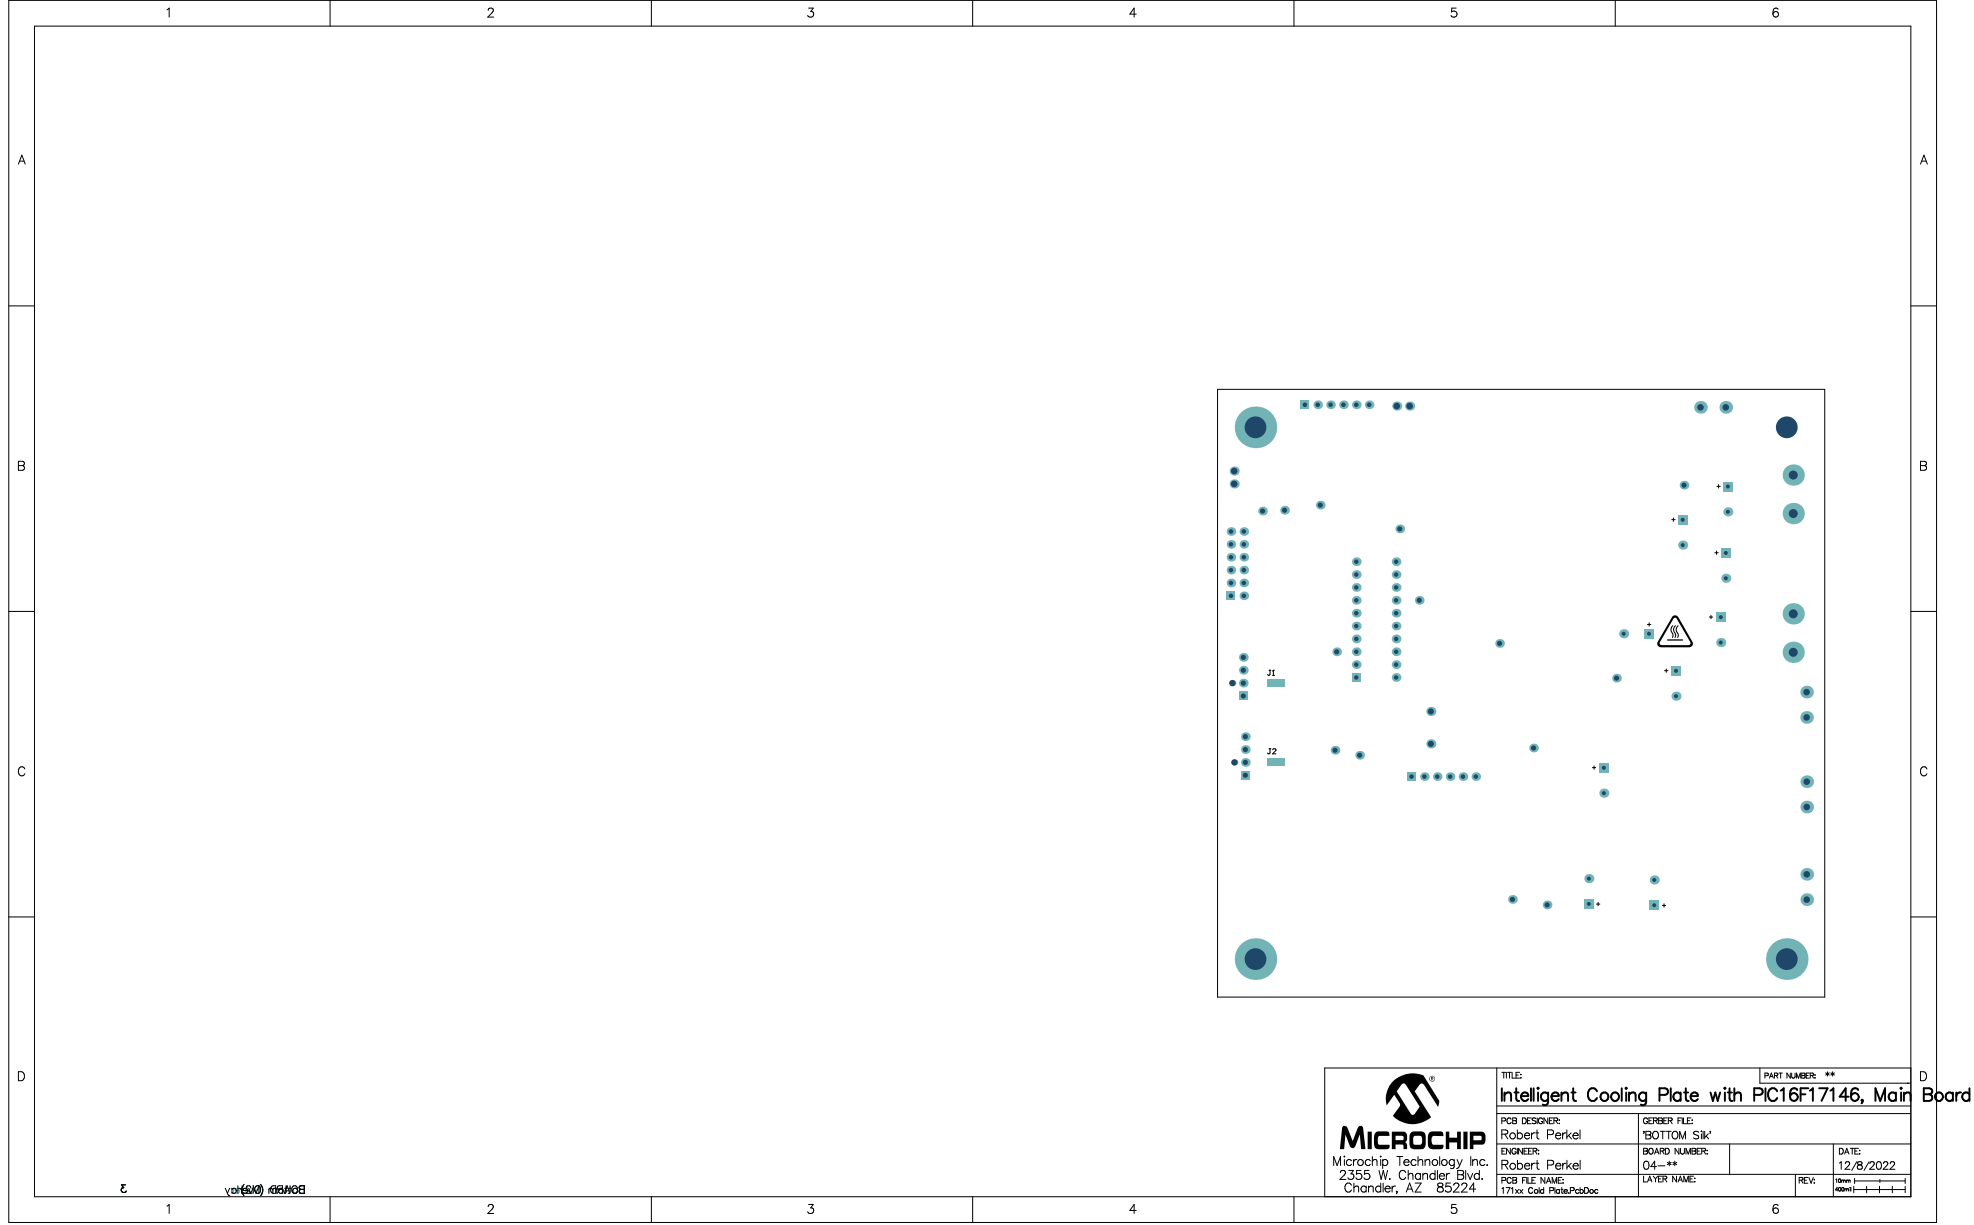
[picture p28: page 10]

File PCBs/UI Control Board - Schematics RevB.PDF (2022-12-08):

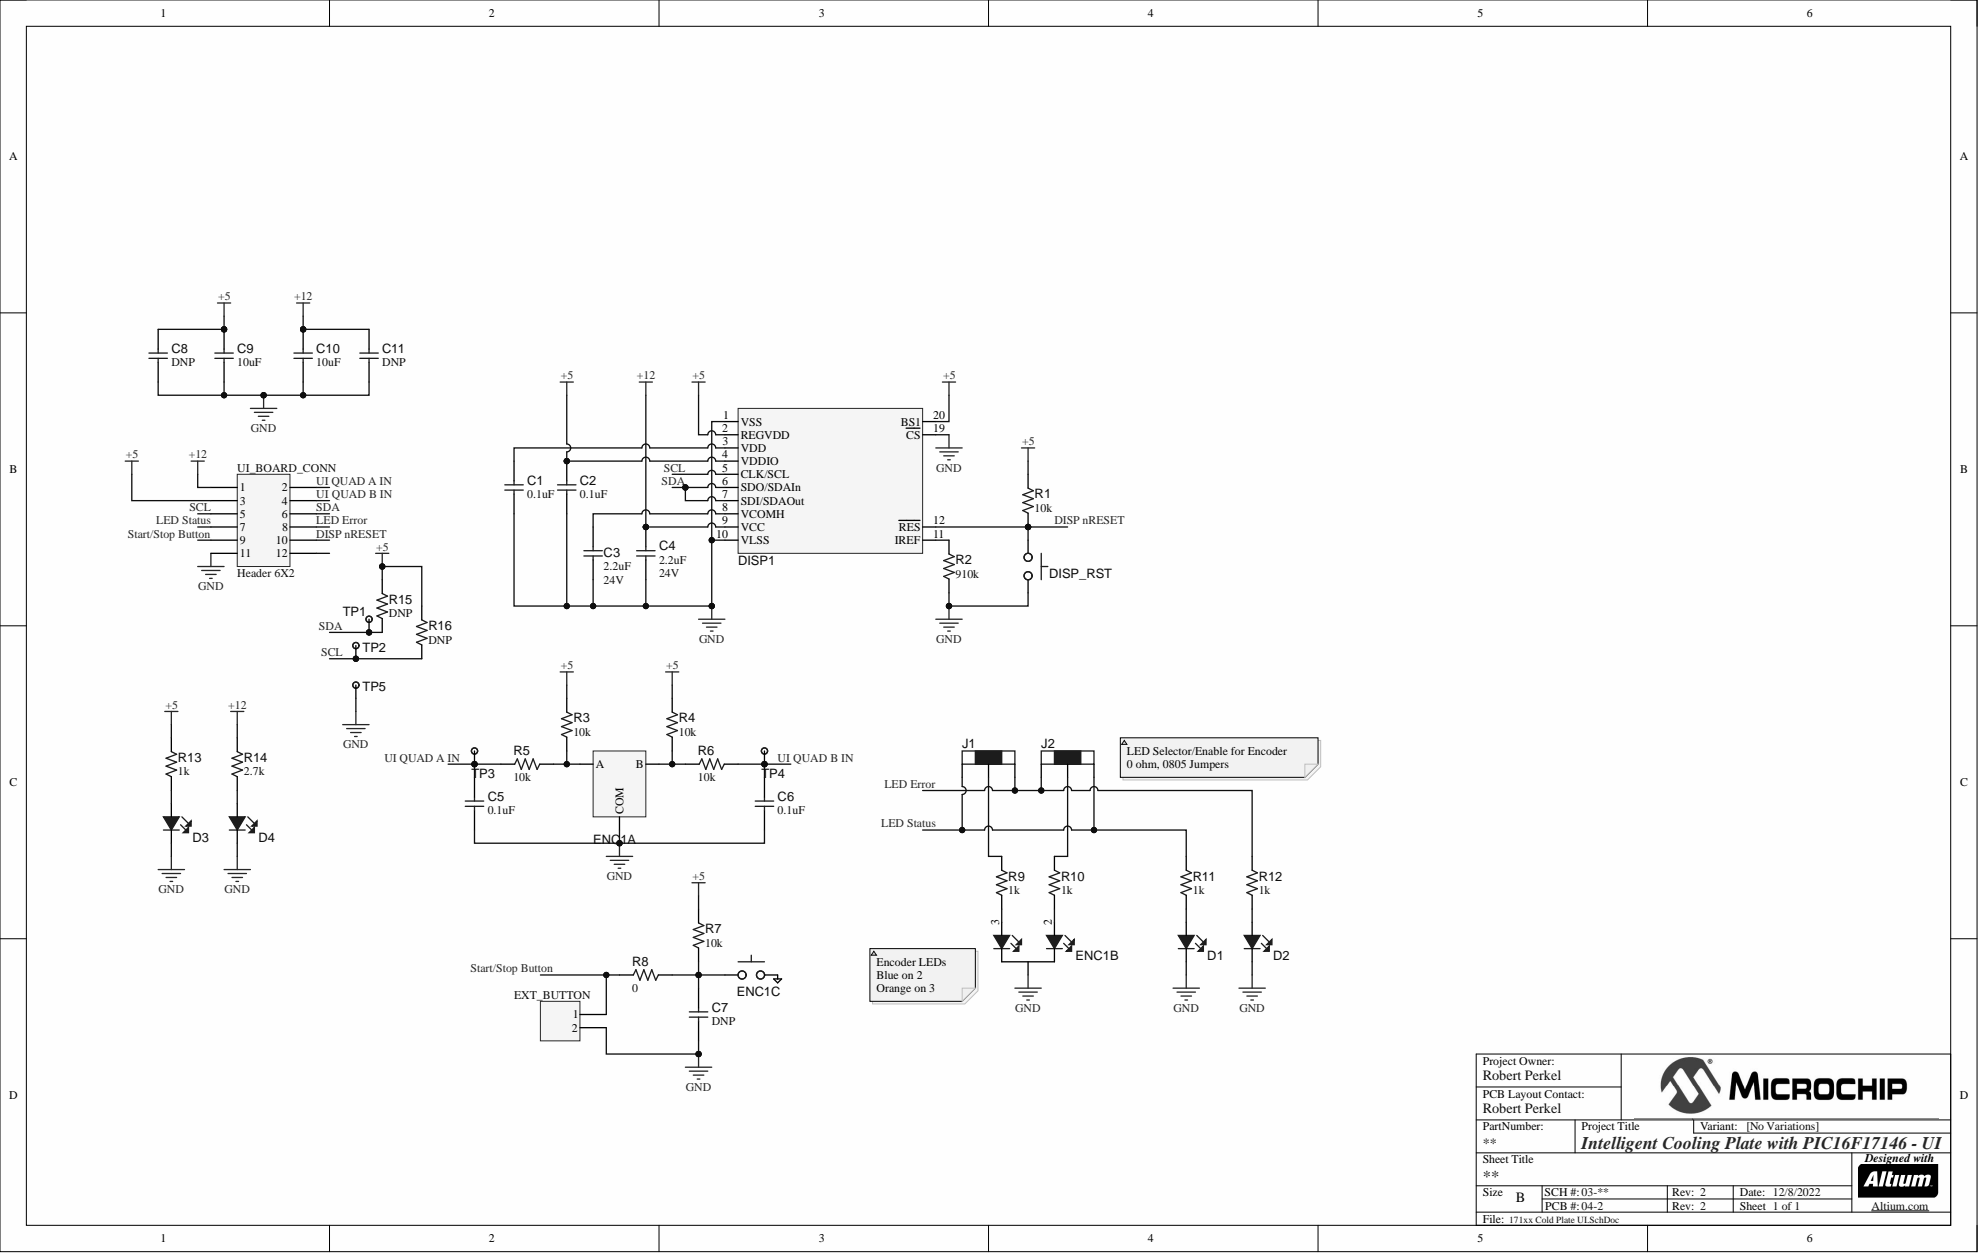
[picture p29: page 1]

SCL | | 5

LED Selector/Enable for Encoder
0 ohm, 0805 Jumpers

Project Title
Intelligent Cooling Plate with PIC16F17146 - UI

Sheet Title ** | Designed with Altium.com

Size B | SCH #: 03-** | Rev: 2 | Date: 12/8/2022

PCB #: 04-2 | Rev: 2 | Sheet

x Cold Plate UI.SchDo

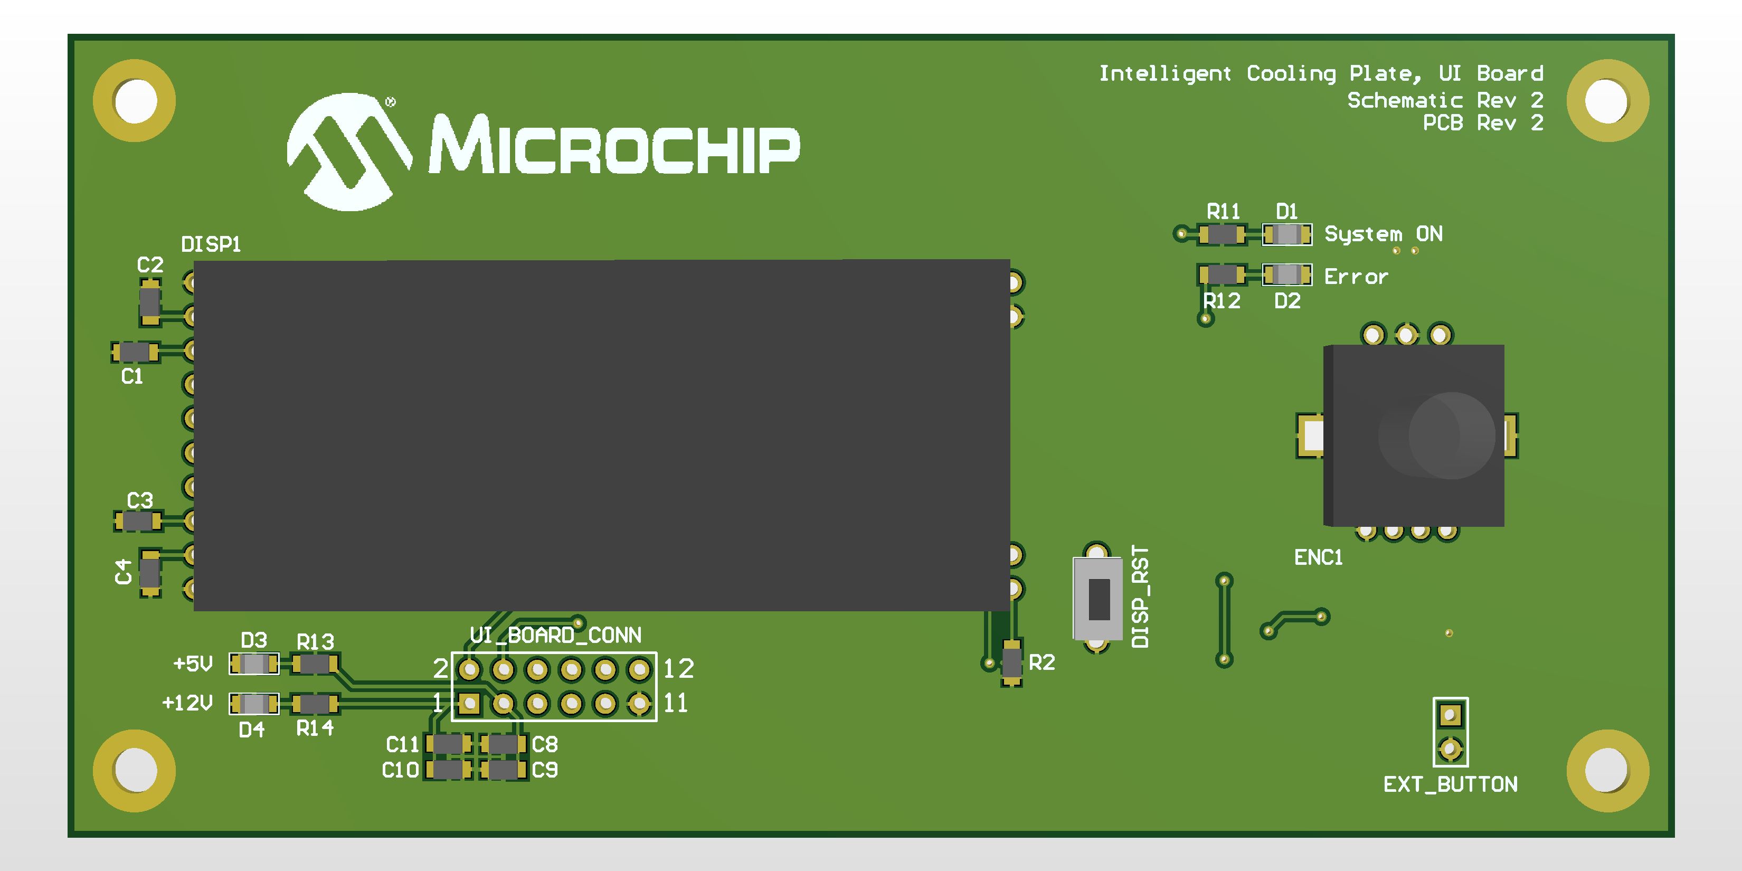
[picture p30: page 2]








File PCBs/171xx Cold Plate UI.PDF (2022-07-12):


SCL | | 5

LED Selector/Enable for Encoder
0 ohm, 0805 Jumpers

Project Title
Analog Cold Plate - UI Board

Sheet Title ** | Designed with Altium.com

Size B | SCH #: 03-** | Rev: 1 | Date: 7/10/2022

PCB #: 04-1 | Rev: 1 | Sheet

x Cold Plate UI.SchDo









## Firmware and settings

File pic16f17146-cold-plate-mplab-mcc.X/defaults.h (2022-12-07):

#ifndef DEFAULTS_H
#define	DEFAULTS_H

#ifdef	__cplusplus
extern "C" {
#endif

//-- Default Values used for resetting EEPROM -- 

//Default to Celsius
#define DEFAULT_TEMP_UNIT 'C'
        
//Default Temperature Limits
#define DEFAULT_MAX_INT_SETTING 70
#define DEFAULT_MAX_HOT_SETTINGS 80
    
//Demo mode is on by default
#define DEFAULT_DEMO_MODE true
    
//Default Plate Set Point
#define DEFAULT_LAST_TEMP_SETTING 10
    
//Default Temperature Hysteresis
//Will turn off at SET_POINT + OVER and on again at SET_POINT + UNDER
#define DEFAULT_TEMP_HYSTER_OVER 1
#define DEFAULT_TEMP_HYSTER_UNDER 1

#define DEFAULT_SHOW_ICONS false

#ifdef	__cplusplus
}
#endif

#endif	/* DEFAULTS_H */

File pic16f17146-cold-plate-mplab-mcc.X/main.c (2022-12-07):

 /*
 * MAIN Generated Driver File
 * 
 * @file main.c
 * 
 * @defgroup main MAIN
 * 
 * @brief This is the generated driver implementation file for the MAIN driver.
 *
 * @version MAIN Driver Version 1.0.0
*/

/*
� [2022] Microchip Technology Inc. and its subsidiaries.

    Subject to your compliance with these terms, you may use Microchip 
    software and any derivatives exclusively with Microchip products. 
    You are responsible for complying with 3rd party license terms  
    applicable to your use of 3rd party software (including open source  
    software) that may accompany Microchip software. SOFTWARE IS ?AS IS.? 
    NO WARRANTIES, WHETHER EXPRESS, IMPLIED OR STATUTORY, APPLY TO THIS 
    SOFTWARE, INCLUDING ANY IMPLIED WARRANTIES OF NON-INFRINGEMENT,  
    MERCHANTABILITY, OR FITNESS FOR A PARTICULAR PURPOSE. IN NO EVENT 
    WILL MICROCHIP BE LIABLE FOR ANY INDIRECT, SPECIAL, PUNITIVE, 
    INCIDENTAL OR CONSEQUENTIAL LOSS, DAMAGE, COST OR EXPENSE OF ANY 
    KIND WHATSOEVER RELATED TO THE SOFTWARE, HOWEVER CAUSED, EVEN IF 
    MICROCHIP HAS BEEN ADVISED OF THE POSSIBILITY OR THE DAMAGES ARE 
    FORESEEABLE. TO THE FULLEST EXTENT ALLOWED BY LAW, MICROCHIP?S 
    TOTAL LIABILITY ON ALL CLAIMS RELATED TO THE SOFTWARE WILL NOT 
    EXCEED AMOUNT OF FEES, IF ANY, YOU PAID DIRECTLY TO MICROCHIP FOR 
    THIS SOFTWARE.
*/
#include "mcc_generated_files/system/system.h"
#include "measurements.h"
#include "fanControl.h"
#include "NTC_ROM.h"
#include "testing.h"
#include "peltierControl.h"
#include "utility.h"
#include "currentSense.h"
#include "OLED.h"
#include "UI.h"
#include "mssp1_host.h"
#include "settings.h"
#include "config.h"
#include "compactPrint.h"

#include <stdint.h>
#include <stdbool.h>
#include <xc.h>

static volatile bool selfCheck = false, dispRefresh = false;

//This is called every 10ms from Timer 0
//DO NOT ADD BLOCKING CODE HERE
void Timer0_1ms_Callback(void)
{
    static volatile uint8_t counter10ms = 1;
    static volatile uint8_t counter100ms = 1;
    static volatile uint16_t counter1s = 1;
    
    if (counter10ms == 10)
    {
        //Call these functions every 10ms
        Measurements_runStateMachine();

        // update breathing effect every 10ms
        encoderControl_updateLEDs();
        
        counter10ms = 0;
    }
    else
    {
        counter10ms++;
    }
    //End of 10ms Period
    
    if (counter100ms == 100)
    {
        counter100ms = 0;
        dispRefresh = true;
    }
    else
    {
        counter100ms++;
    }
    
    if (counter1s == 1000)
    {
        counter1s = 0;
        
        //Call these functions every second
        
        //Update RPMs
        fanControl_timerCallback();
        
        //Set flags
        selfCheck = true;
    }
    else
    {
        counter1s++;
    }
}

int main(void)
{
    SYSTEM_Initialize();    
    UART1_TransmitEnable();
       
    // init i2c
    initI2CPins();
    MSSP_HostInit();
    
#ifdef DEBUG_PRINT
    compactPrint_sendStringWithNewline("\r\n--STARTING UP--");
#endif
    
    //Print the Reset Registers
    System_printResetRegisters();
    
    //Init and Verify Settings / EEPROM
    settings_init();
    
    //Init Fan Controls
    fanControl_init();
    
    //Init Temp Monitor
    Measurements_init();
    
    //Init Current Sense Circuit
    currentSense_init();
    
    //Init Peltier Control
    peltierControl_init();
            
    //Configure 10ms Callback
    Timer0_OverflowCallbackRegister(&Timer0_1ms_Callback);
    
    //Setup ADC Results Callback
    ADCC_SetADTIInterruptHandler(&Measurements_loadResults);
    
    // Enable the Global Interrupts 
    INTERRUPT_GlobalInterruptEnable(); 

    // Enable the Peripheral Interrupts 
    INTERRUPT_PeripheralInterruptEnable(); 
        
    //Run Gain Self-Test
    //Must be run before Timer0 starts!
    currentSense_selfTest();
        
    //Start Timer 0 (10ms)
    Timer0_Start();
    
    //Pull local coy of settngs before populating UI
    settingMenus_populateSettings();
    
    //Init OLED Display
    OLED_init();

    //Start Fan Controller
    fanControl_start();
    
    // Enable PWM
    LED_PWM_Enable();
    
#ifdef DEBUG_PRINT
    compactPrint_sendStringWithNewline("--STARTUP DONE--\r\n");
#endif    
    while(1)
    {        
        //Note: This must occur every 250ms to 2s or WWDT will reset
        if (selfCheck)
        {
            selfCheck = false;
                        
            //Run Periodic Self-Check
            peltierControl_periodicCheck();
            
#ifdef DEBUG_TELEMETRY
#ifdef DEBUG_PRINT
            compactPrint_sendDebugTelemetry();
#endif
#ifdef DEBUG_RAW_VALUES
            compactPrint_sendRawValues();
#endif
#endif
        }
        
        if(dispRefresh){ // update UI every 100ms
            UI_refresh();
            dispRefresh = false;
        }

    }    
}

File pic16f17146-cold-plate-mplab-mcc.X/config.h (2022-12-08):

#ifndef CONFIG_H
#define	CONFIG_H

#ifdef	__cplusplus
extern "C" {
#endif

#include <stdbool.h>
    
//If defined, telemetry will be sent via UART (Global Enable)
#define DEBUG_TELEMETRY 
    
//If defined, debug messages will be sent via UART
#define DEBUG_PRINT
    
//If defined, raw ADC readings will be sent via UART
//#define DEBUG_RAW_VALUES
    
//If defined, UI will show error messages
#define UI_ERRORS
    
//Lowest allowed temperature in demo mode
#define DEMO_TEMP_LIMIT_LOW 5

//Lowest allowed temperature in not demo mode
#define TEMP_LIMIT_LOW -20
    
//Maximum allowed temperature to set
#define TEMP_LIMIT_MAX 25
    
//Minimum Heatsink Temperature (to be considered connected)
#define TEMP_NTC_HOT_OPEN 15
    
//Minimum Heatsink Temperature (to be considered connected)
#define TEMP_NTC_COLD_OPEN 40
    
//Max Temperature before 100% Fan Speed
#define HEATSINK_TEMP_FAN_MAX 60
    
//Base Temperature for Fan Speed Calculations
#define HEATSINK_TEMP_FAN_MIN 28
    
//Min Fan Speed (1 degree per C above)
#define HEATSINK_TEMP_SLOPE 40
        
//Peltier Current Limit (100s of mA)
#define PELTIER_CURRENT_MAX 100

//Minimum Peltier current for detection
#define PELTIER_CURRENT_MIN 10
    
//Defines the gain the system is in
#define SYSTEM_GAIN GAIN_8
    
//Allowed error margin for gain (+/-)
#define GAIN_TOLERANCE 0.25
    
#ifdef	__cplusplus
}
#endif

#endif	/* CONFIG_H */

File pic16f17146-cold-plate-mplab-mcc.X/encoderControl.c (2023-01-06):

#include "encoderControl.h"


// Return total encoder moves since last poll
int16_t encoderControl_getMoves(void){
    static uint16_t oldTimer1 = 0;
    static uint16_t oldTimer3 = 0;
    
    uint16_t newTimer1, newTimer3, netTimer1, netTimer3;
    int16_t encoder;
    
    newTimer1 = Timer1_Read();
    newTimer3 = Timer3_Read();
    
    netTimer1 = 0;
    netTimer3 = 0;
    
    if(newTimer1 < oldTimer1){
        // Rollover occurred
        // Add an offset to the net value and clear the old value
        netTimer1 = 0xFFFF - oldTimer1;
        oldTimer1 = 0;
    }
    
     if(newTimer3 < oldTimer3){
        // Rollover occurred
        // Add an offset to the net value and clear the old value
        netTimer3 = 0xFFFF - oldTimer3;
        oldTimer3 = 0;
    }
    
    //Find the net change
    netTimer1 += newTimer1 - oldTimer1;
    netTimer3 += newTimer3 - oldTimer3;
    
    // Calculate the net encoder change
    encoder = (int16_t)(netTimer3 - netTimer1);
    
    oldTimer1 = newTimer1;
    oldTimer3 = newTimer3;
    
    return encoder;
}

// called every 10ms
void encoderControl_updateLEDs(void){
    switch(UI_getState()){
        case STANDBY:
            encoderControl_breatheLED(PURPLE);
            break;
        case ERROR:
            encoderControl_setColor(ORANGE);
            break;
        case MENU:
            if(!UI_isRunning()){
                encoderControl_setColor(PURPLE);
            } else { // If running
                // comparison bases LED off current value, not hysteresis. Makes more sense than
                // current temp being at set temp, but not show via LED it's at set temp
                if(Measurements_getLastColdTemp() > settingMenus_getTargetTemp()){
                    encoderControl_breatheLED(BLUE);
                } else {
                    encoderControl_setColor(BLUE);
                }
            }
            break;
        case RUNNING:
            // PWM while cooling, Solid blue at temp
            if(Measurements_getLastColdTemp() > settingMenus_getTargetTemp()){
                encoderControl_breatheLED(BLUE);
            } else {
                encoderControl_setColor(BLUE);
            }
            break;
    }
}

void encoderControl_setColor(EncoderLEDState color){
    switch(color){
        case BLUE:
            encoderControl_setLEDValue(65535, 0);
            break;
        case ORANGE:
            encoderControl_setLEDValue(0, 65535);
            break;
        case PURPLE:
            encoderControl_setLEDValue(65535, 65535);
            break;
        case OFF:
            encoderControl_setLEDValue(0, 0);
            break;
    }
}

// set encoder LED colors
void encoderControl_setLEDValue(uint16_t blue, uint16_t orange){
    LED_PWM_SetSlice1Output1DutyCycleRegister(blue);
    LED_PWM_SetSlice1Output2DutyCycleRegister(orange);
    LED_PWM_LoadBufferRegisters();
}

// number of PWM increments (PWM functions scale to each intensity level is 10% of increments)
#define PWM_MAX_VAL 200
#define PWM_increments 100


// if breathing, call every 10ms
void encoderControl_breatheLED(EncoderLEDState color){
    enum BREATHING_STATES {RAMPING_UP, PEAK, RAMPING_DOWN, BOTTOM};
    static enum BREATHING_STATES breathing_state = RAMPING_UP;
    static uint16_t delay_counter = 0;
    static uint8_t PWM_intensity = 0; // value between 0 - PWM_increments
    
    switch(breathing_state){
        case RAMPING_UP: 
            PWM_intensity+=1;
            encoderControl_setLEDValue((int)(PWM_MAX_VAL/PWM_increments) * PWM_intensity, (color == PURPLE) ? (int)(PWM_MAX_VAL/PWM_increments) * PWM_intensity : 0);
            if(PWM_intensity >= PWM_increments){ // when intensity is maxed out
                breathing_state = PEAK;
                delay_counter = 0;
            }
            break;
        case PEAK: // wait 500ms before ramping down
            if(delay_counter >= 50){
                breathing_state = RAMPING_DOWN;
                delay_counter = 0;
            }
            break;
        case RAMPING_DOWN:
            PWM_intensity-=1;
            encoderControl_setLEDValue((int)(PWM_MAX_VAL/PWM_increments) * PWM_intensity, (color == PURPLE) ? (int)(PWM_MAX_VAL/PWM_increments) * PWM_intensity : 0);

            if(PWM_intensity <= 0){
                breathing_state = BOTTOM;
                delay_counter = 0;
            }
            break;
        case BOTTOM:
            if(delay_counter >= 50){ // wait 50 ms before restarting cycle
                breathing_state = RAMPING_UP;
                delay_counter = 0;
            }
            break;
    }
    delay_counter++;
}

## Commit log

2022-07-12 MPAE-14640: Added PCB files
2022-07-13 MPAE-14640: Started on Fan Control / Temp Control
2022-07-13 MPAE-14640: Improvements to main and fan control
2022-07-29 MPAE-14640: Fixed INT temperature monitor
    [fanControl.c, main.c, tempMonitor.c]
2022-07-29 MPAE-14640: Added code to start measuring NTC thermistors.
2022-08-01 MPAE-14640: Added PWM Period INT
2022-08-01 MPAE-14640: Improved DAC glitch protection
    [currentSense.c, fanControl.c, main.c]
2022-08-15 MPAE-14640: Added UI Code
    [Config_A.txt, Config_B.txt, Config_C.txt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]
2022-08-18 MPAE-14640: Standby temperature extra char fix
2022-08-22 MPAE-14640: Added CRC memory
    [Config_A.txt, Config_B.txt, Config_C.txt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]
2022-08-22 MPAE-14640: Added Current Sense Calibration
2022-08-23 MPAE-14640: Added new power error detector. (Not implemented yet)
    [currentSense.c, main.c, tempMonitor.c]
2022-08-24 MPAE-14640: Button press debounce changed to polling
2022-08-24 MPAE-14640: Improved telemetry print. Added block for printf
2022-08-29 MPAE-14640: Reduced code footprint by 30% of device memory
2022-08-29 MPAE-14640: Removed stack overflow dependency & fixed incomplete prototypes
    [UI.c, main.c]
2022-09-01 MPAE-14640: Removed UI limit current functionality
2022-09-01 MPAE-14640: Added error checking to UI
    [UI.c, config.h, encoderControl.c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]
2022-09-07 MPAE-14640: Fixed CRC. Temp state machine. Max current fixes
    [config.h, currentSense.c, main.c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]
2022-09-09 MPAE-14640: Added show icons option & redesign LED state machine
    [UI.c, config.h, encoderControl.c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]
2022-09-15 MPAE-14640: Implemented rotary encoder wrap-around vs resetting the timer
    [encoderControl.c]
2022-09-19 MPAE-14640: Removed glitch pulses from PWM LED
    [encoderControl.c, main.c]
2022-09-19 MPAE-14640: LED colors reflect current state
2022-09-20 MPAE-14640: Flipped heatsink icon
2022-09-22 MPAE-14640: Started on compact print. Started on fan -> speed control
2022-09-27 MPAE-14640: added compact print
2022-09-27 MPAE-14640: Fixed CRC. Removed printf
    [compactPrint.c, currentSense.c, defaults.h]
2022-10-10 MPAE-14640: Errors only appear when plate is running
    [UI.c]
2022-10-25 MPAE-14640: Added fan control
2022-10-28 MPAE-14640: Added new errors. Increased operating frequency. Synced current comparator. Added OCP
    [config.h, currentSense.c]
2022-10-28 MPAE-14640: Improved cold plate code
2022-11-08 MPAE-14640: Modified current sense
2022-12-01 MPAE-14640: Added current monitoring to UI
2022-12-01 MPAE-14640: Added 3d printed CAD files
    [UI_mount.FCStd, encoder_cover.FCStd, knob-skinny-12mm.FCStd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]
2022-12-01 MPAE-14640: Fixed calculations. Enabled Power Detector
    [measurements.c]
2022-12-01 MPAE-14640: Enabled PWM
2022-12-01 MPAE-14640: Removed LED software PWM code, changed for hardware PWM
2022-12-02 MPAE-14640: Added raw ADC print
2022-12-05 MPAE-14640: Added mechanical files. Started code cleanup
    [Bottom Plate.dxf, PCB Mounting.dxf, PSU Mounting.dxf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]
2022-12-07 MPAE-14640: Added new debug prints for comparator status
2022-12-07 MPAE-14640: Improved current monitoring code. Added more debug telemetry
2022-12-07 MPAE-14640: Fixed error not clearing
    [UI.c]
2022-12-07 MPAE-14640: Fixed OCP not triggering. Adjusted debug messages
    [compactPrint.c, currentSense.c, main.c]
2022-12-08 MPAE-14640: Removed OCP interrupt
2022-12-08 MPAE-14640: Added .obj files
    [UI_mount.FCStd, UI_mount.obj, encoder_cover.FCStd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]
2022-12-08 MPAE-14640: Added new PCB files
2022-12-09 MPAE-14640: Added info about PCBs
2022-12-12 MPAE-14640: Added PCB comment
2023-01-04 MPAE-14640: Replaced cold plate images
2023-01-06 MPAE-15313: status LED ignores hysteresis
